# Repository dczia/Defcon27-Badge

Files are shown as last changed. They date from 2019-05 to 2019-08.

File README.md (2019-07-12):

# Defcon27-Badge

```
 ____   ____ ______             ____   ____ ____ _____
|  _ \ / ___|__  (_) __ _      |  _ \ / ___|___ \___  |
| | | | |     / /| |/ _` |_____| | | | |     __) | / /
| |_| | |___ / /_| | (_| |_____| |_| | |___ / __/ / /
|____/ \____/____|_|\__,_|     |____/ \____|_____/_/
```

# Lazer Theramin Synth Badge

This year we wanted to do something different. Our idea is to use two laser time of flight sensors that can measure the distance of your hands moving around infront of the badge to control a synthesizer to create a laser theremin.

- 64Mhz Arm CortexM4F with Bluetooth 5
- 5 Mechanical Clicky Low Profile Key Switches
- Rotary Encoder with Click Button
- OLED Display
- Onboard Speaker and Amplifier!
- 1/8" Headphone Out Audio Jack
- SD Card Storage
- RGB Leds
- 2 SAO / "Shitty Add-On" Connectors

# Hardware Detail

- Rigado BMD-340 aka NRF52 Microconroller
  - Bluetooth, Lots of IO's, Fast, Small, Low Power, and cheap ~ $12
  - https://www.rigado.com/products/modules/bmd-340/

- Laser Time of Flight Sensors - Dev modules are from Adafruit 
  - https://www.adafruit.com/product/3317

- DAC / Amplifier - mediumRehr Audio™

- Speaker - Oval 1watt onboard speaker

- Buttons - Kalih Low Profile White Clicky Keyswitches. Oh yeah. This is the shit right here.
  - https://novelkeys.xyz/collections/switches/products/kailh-low-profile-switches

- Keycaps - Note, the low profile caps are for the Kalih low profile switches only. 
  - https://novelkeys.xyz/collections/keycaps/products/kailh-low-profile-keycaps-blank
  
- LEDs
  - Neopixel RGB

- Screen - SSD1306 OLED

- SD Card

# Software

- Environment is GNU ARM GCC with your choice of IDE

- Programming can be done via a J-Link Segger or by SD Card (coming soon)

- Uses Nordic SoftDevice version XXX

- See [EnvironmentSetup](Software/EnvironmentSetup.md) for more info

# Board

- Designed in KiCad

# Documentation

- [Board Build Guide](BuildGuide.md)
- [EnvironmentSetup](Software/EnvironmentSetup.md)

# Links to relevant information

- [Documentation library - nordicsemi.com](https://www.nordicsemi.com/DocLib)

- DC801 Party Badge - Good source for setting up dev env, and seeing some Rigado code in action - https://github.com/DC801/DC26PartyBadge

- oxvox - Rigado based pwm synth - https://github.com/mediumrehr/oxvox

- Basic audio synthesis with an Arduino - https://makezine.com/projects/make-35/advanced-arduino-sound-synthesis/

- mintysynth - simple arduino synth - https://mintysynth.com/

- Nordic PWM Driver info: https://infocenter.nordicsemi.com/index.jsp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

- PWM Primer - https://provideyourown.com/2011/analogwrite-convert-pwm-to-voltage/

# Devboard pinout

BMD-340-DK Pinout

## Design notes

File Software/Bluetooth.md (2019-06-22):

# DC25 Bluetooth Protocol

So you might have noticed that multiple badges talked to each other this year.  How did we do that?  Well, the magic is in the BLE advertising packet.

This packet can be up to 31 bytes long, and consists of a series of 'blocks'.  Each block starts with a byte that indicates how many bytes follow in this block, next byte is the block type, then the rest of the bytes are the block content.

The key parts of the DC26 and the DC25 protocol before it are the Appearance value, which must be DC19, and the manufacturer block, which defines which badge this is.  The rest of the packet can be whatever you want it to be.

Here's a visual of a packet that my DC801 badge broadcasted:

Advertising Layout

Let's break this down:

General notes:  This is the order the DC801 badge sent the blocks, but in reality the order doesn't matter.

First off, Appearance. 4 total bytes, but the length byte doesn't count, so 03 bytes long.  Type is 0x19 to indicate this is a BLE Appearance block, then the Appearance ID of DC26.  If it was a DC25 badge, the ID would be DC19 - yeah, we changed it up a little

Next up, Flags.  The Flags mark what kind of advertisement this is.  With our flags of 06 we indicate we are general connectable and that we'll show up in bluetooth scans.  Open your phone and look for nearby devices - your DC801 badge will show up there.  We don't offer any actual services, so connecting to the badge is a bit of a honeypit to slow down people attempting to figure out the game protocol.

Next block, Manufacturer.  This block is a little special.  The first two bytes is the manufacturer ID, which is byte swapped 'on the wire' as it were: 0108 is 0801.  Some groups actually registered with the BLE group and got a real ID - check out Bender or Queercon.  We didn't get the paperwork done in time, so we used a fake ID that was not in use for 0801.  Now, there are some bytes that follow.  Those bytes can be any length (up to the 31 total, remember), and can mean anything you want them to mean.  In our case:

0108 - DC801 is the manufacturer
8 bytes - which contains your score, your clan, and a checksum of your score with some bytes scrambled:
 - 0: Command to DCFurs badges - 0x35 indicates rabies infection
 - 1: Score byte 0
 - 2: Score byte 3
 - 3: CRC high byte
 - 4: Score byte 2
 - 5: CRC low byte
 - 6: Score byte 1
 - 7: Clan ID
 
The score can be as big as 32 bytes, unsigned.  I put it through a 'custom' CRC seeded with the polynum 0x0801 to verify that the score hasn't been tampered with - but I know someone is gonna figure that out, but I'm slowing you down a little.  Same for swapping up the bytes of the score.

However, bytes 1-6 are different if the badge is a 'god mode' badge sending a command - see [godmode.c](godmode.c) for more specific info, but we support these commands:

 - Sheep mode - user badge gets stuck in a loop showing sheep pictures
 - Party mode - user badge gets stuck showing an animated sheep and some LEDs
 - Score points - send the user badge some points, + or -
 - Score modifier - send the user a score percentage modifier
 - Beep - make the user badge beep

Last block is a type 09, which is the Long Name.  This part of the BLE stack will show up as the name if you scan for a device.  Again, it's 8 chars, always, padded with 00 if shorter.  Other badges didn't even look at this, it was just for showing up in bluetooth scans.  68616d7374657200 is ASCII 'hamster'.

##Party

The plan was to show a scoreboard at the party, but... time got in the way, so it didn't happen.  Ah well.  Next year.

How did you like it?  Let me know!  [@hamster](http://twitter.com/hamster)

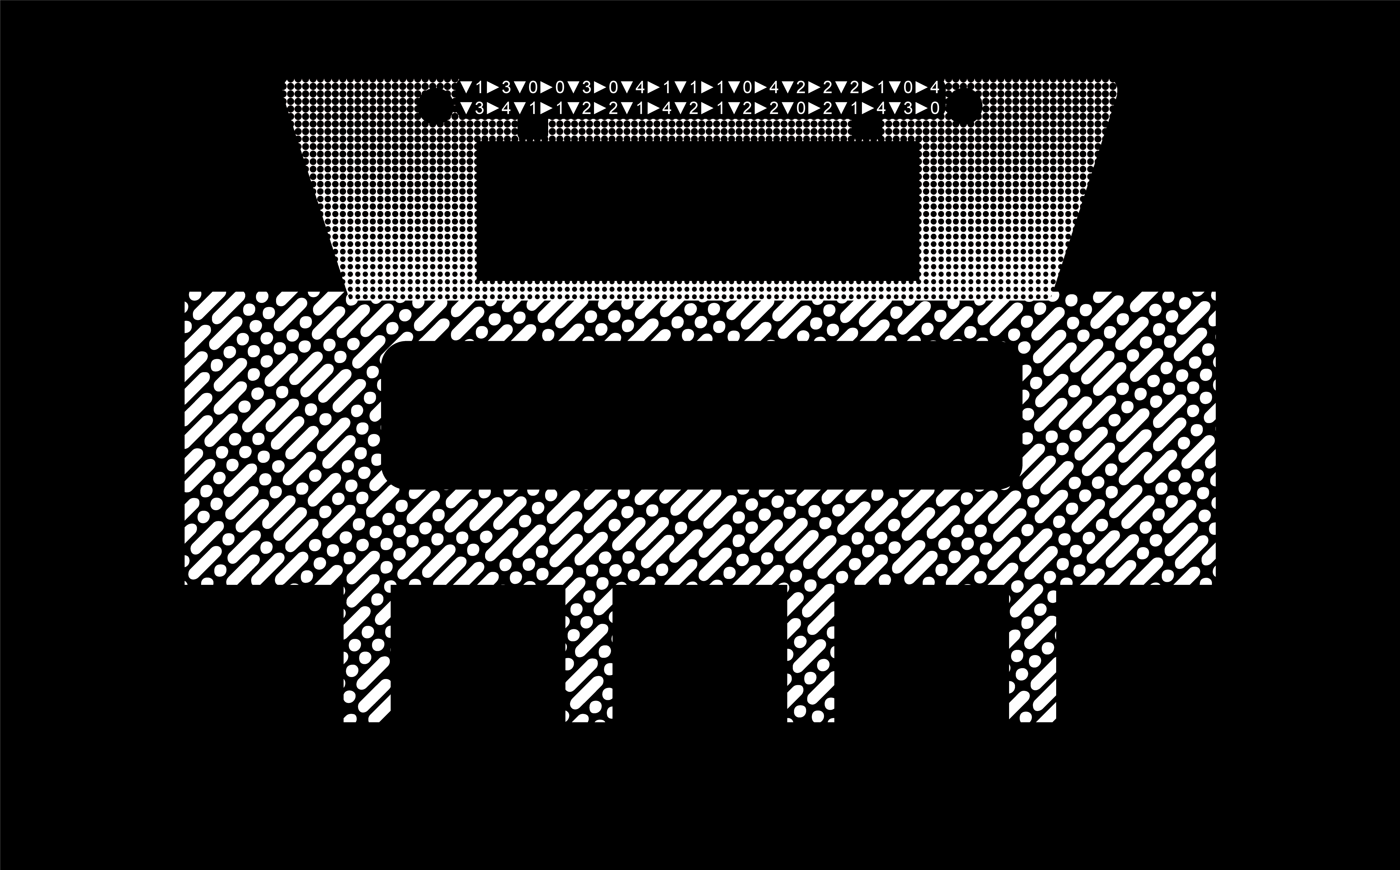
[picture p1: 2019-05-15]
Hardware/Images/silk-art.png

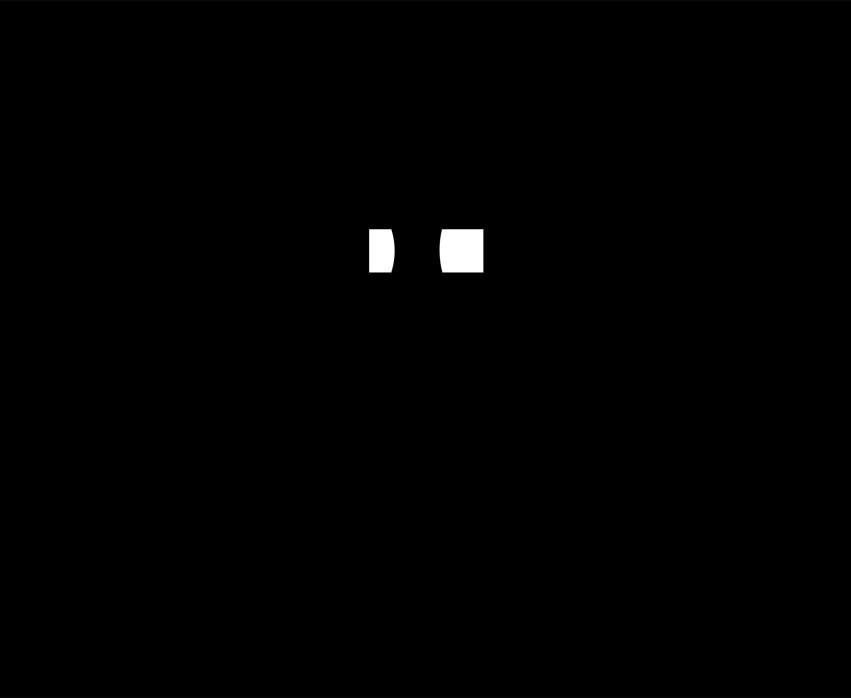
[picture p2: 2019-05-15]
Hardware/Images/copper-reels.png

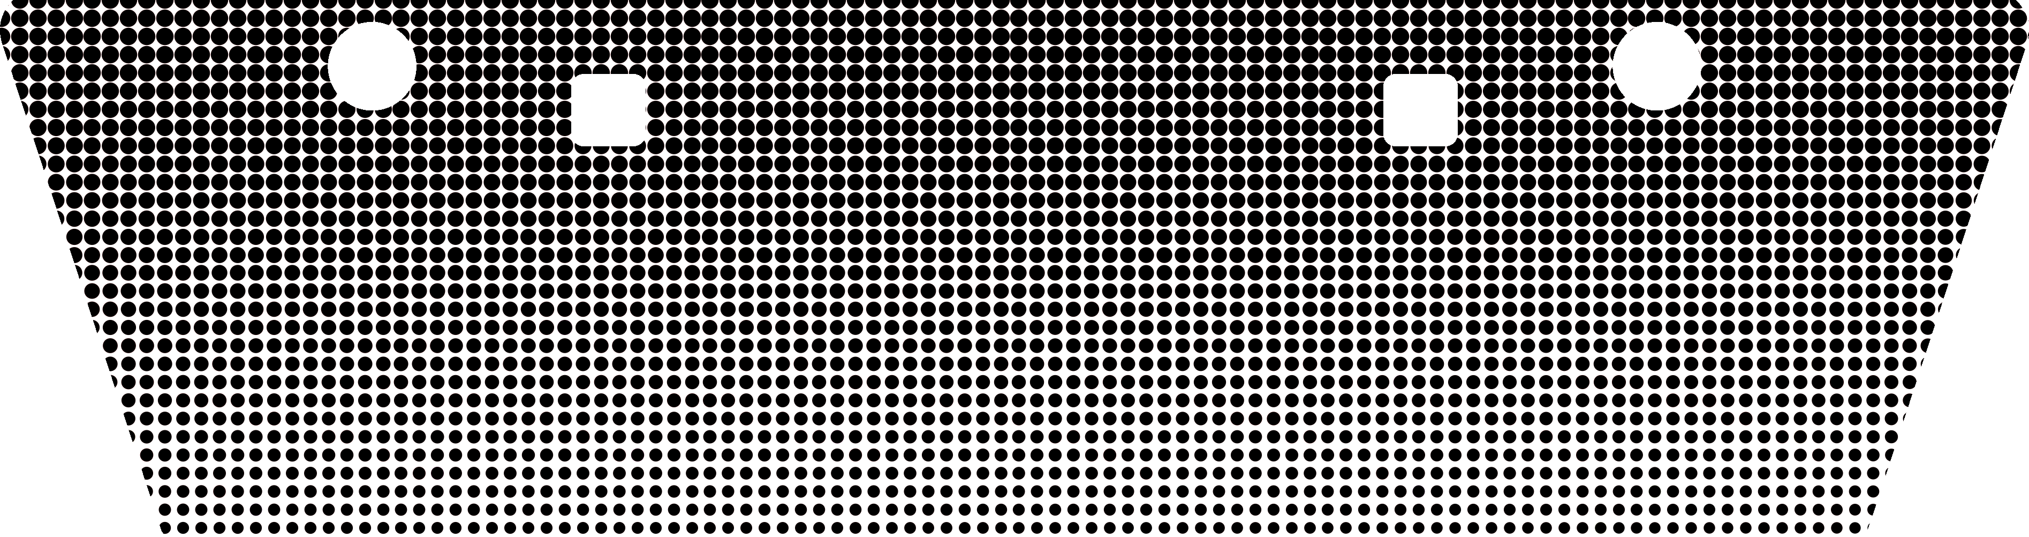
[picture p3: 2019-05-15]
Hardware/Images/halftone2.png

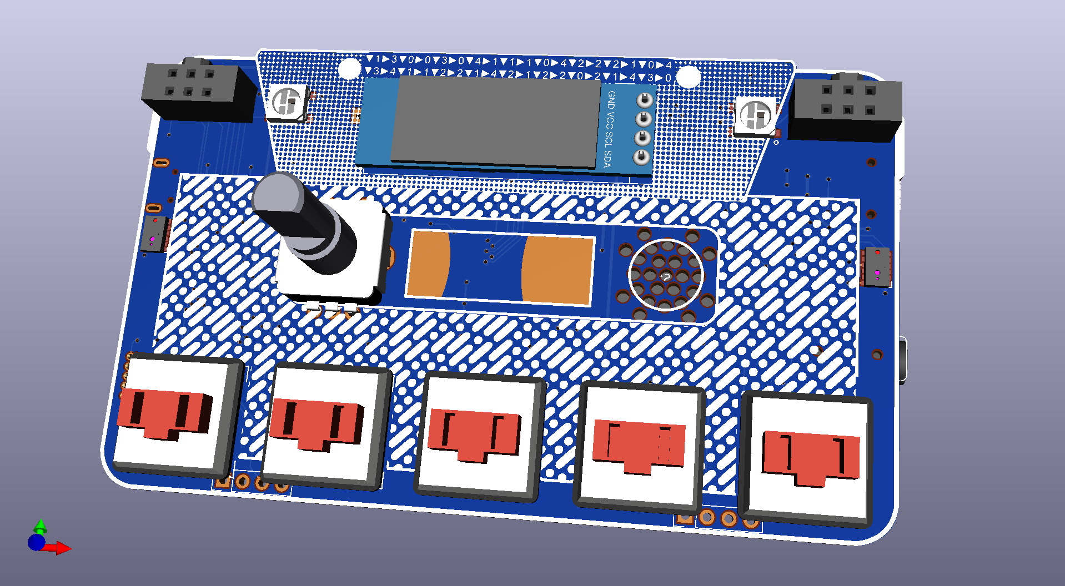
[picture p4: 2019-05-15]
Hardware/Images/laser-theremin-front-4.png

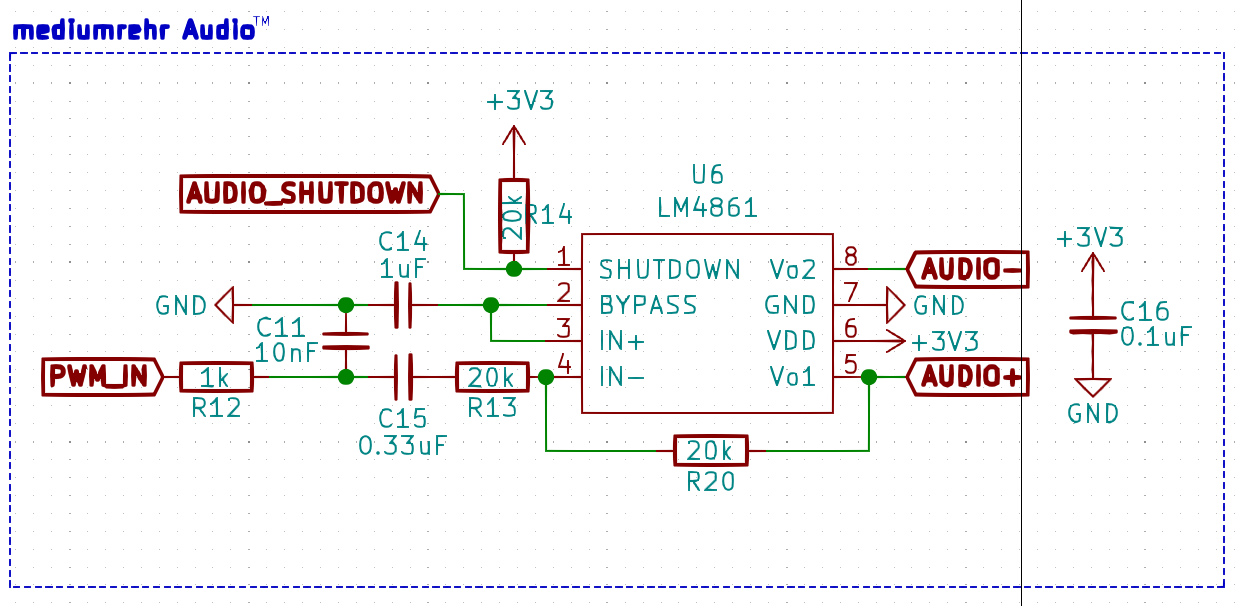
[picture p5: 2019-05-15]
Hardware/Images/mediumrehr-audio.PNG

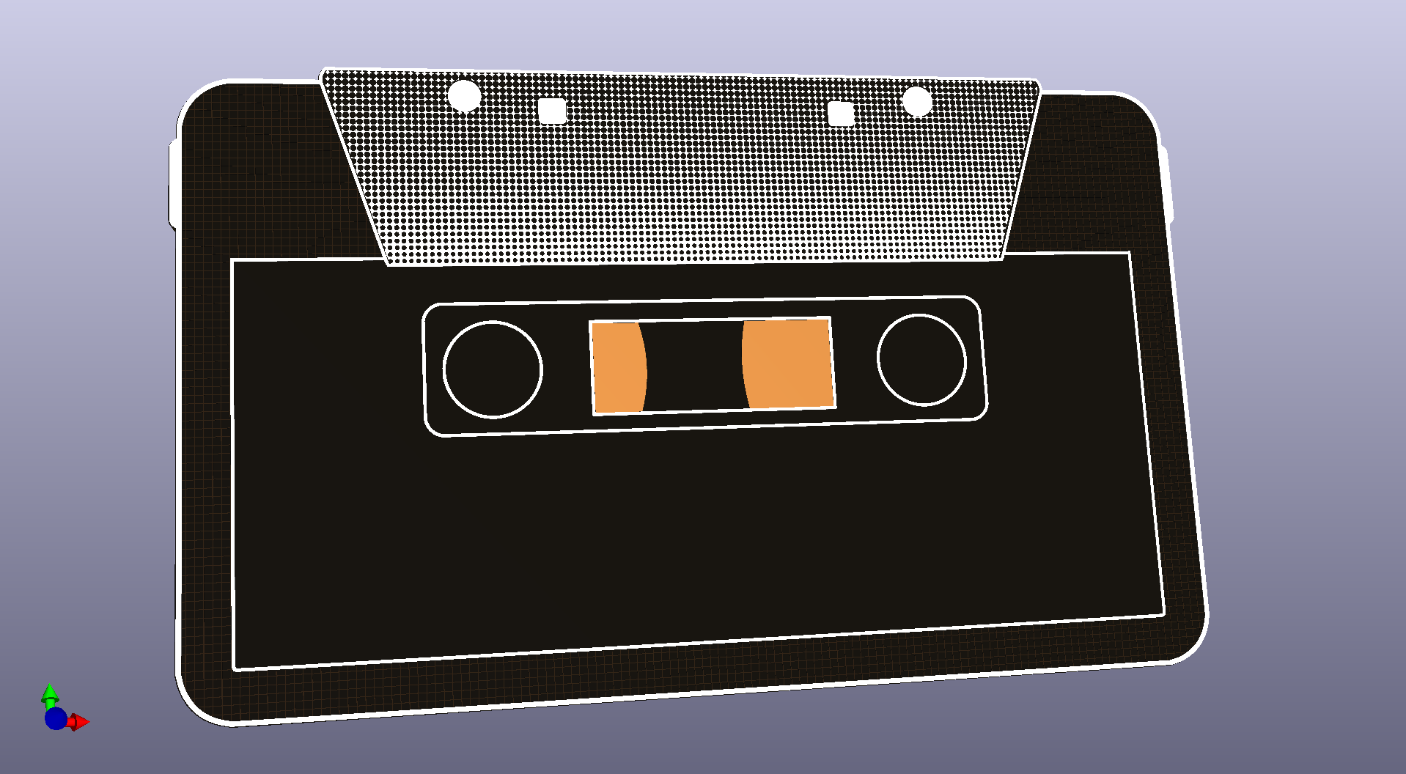
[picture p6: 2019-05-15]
Hardware/Images/laser-theremin-front.png

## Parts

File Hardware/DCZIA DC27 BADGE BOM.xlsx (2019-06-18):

Refdes | Manufacturer | Part Number | Seeed OPL | Other supplier | Description | Package | Cost Each (assumes 100 unit pricing) | Qty per board | Stuff? | QOH | Needed | To Order | Cost Per Board | Qty ordered | Actual Cost | Supplier | Seeed OPL
To Stuff Later
BT1 |  |  |  | https://www.aliexpress.com/item/32323069094.html?spm=a2g0s.9042311.0.0.3da24c4d4QbjF6 | 3xAAA Battery Box |  | 0.28 | 1 |  |  |  |  | 0.28
SW2,SW3,SW4,SW5,SW6 |  | Kaihl Switches |  |  |  |  | 0.66 | 5 |  |  |  |  | 3.3
LS1 |  |  |  | https://www.aliexpress.com/item/20pcs-lot-Acoustic-Speaker-2415-1524-Oval-Tablet-Phone-MP3-Speaker-1W-8-Ohms-L24MMxW15MM/1680397983.html | Speaker, 24x15mm |  | 0.33 | 1 |  |  |  |  | 0.33
OLED |  |  |  |  | OLED display
Virtual, Non-stuff
J1 |  |  |  |  | 2x10 1.27 header, JTAG |  |  |  | N |  |  |  | 0
J5,J9 |  |  |  |  | Rack |  |  |  | N
J7 |  |  |  |  | OLED connector |  |  |  | N
J13 |  |  |  |  | TagConnect |  |  |  | N
J6,J8,J10,J11,J12 |  |  |  |  | Test points |  |  |  | N
X1,X2 |  |  |  |  | SAO 1.69bis |  |  |  | N |  |  |  | 0
R21,R22 |  |  | RC0402JR-074K7L |  | 4.7k DNS | 0402 | 0.0008 | 2 |  |  |  |  | 0.0016
SW7 |  |  | 311130001 |  | Rotary encoder, 12mm DNS |  | 0.61 | 1 |  | m |  |  | 0.61
Stuff at Fab
C1,C2,C7,C10,C16,C17,C18 |  |  | 302010024 |  | 0.1uF Cap | 0402 | 0.01 | 12 |  |  |  |  | 0.12
C3,C5,C15 |  |  | 302010003 |  | 1uF | 0402 | 0.01 | 3 |  |  |  |  | 0.03
C4,C6 |  |  | 302010019 |  | 4.7uF | 0402 | 0.01 | 2 |  |  |  |  | 0.02
C8 |  |  | 302010171 |  | 22uF | 0805 | 0.024 | 1 |  | m |  |  | 0.024
C9 |  |  | 302010005 |  | 1nF | 0402 | 0.01 | 1 |  |  |  |  | 0.01
C11 |  |  | 302010006 |  | 10nF | 0402 | 0.01 | 1 |  |  |  |  | 0.01
C12,C13 |  |  | 302010007 |  | 47pf | 0402 | 0.01 | 2 |  |  |  |  | 0.02
C14 |  |  | CL05A334KQ5NNNC |  | 0.33uF | 0402 | 0.0115 | 1 |  | m |  |  | 0.0115
D1,D12,D13 |  | B5819W | 304020034 |  | Schottky | SOD-123 | 0.023 | 1 |  |  |  |  | 0.023
D2 |  | CESD5V0AP | 304050003 |  | TVS diode | SOT-23 | 0.032 | 1 |  | skip |  |  | 0.032
D3,D4 |  | 1N4148 | 1N4148WS |  | General purpose diode | SOD-323 | 0.0149 | 2 |  |  |  |  | 0.0298
D7,D8,D9,D10,D11 |  |  | 19-217/R6C-AL1M2VY/3T |  | Red LED | 0603 | 0.0232 | 5 |  | m |  |  | 0.116
J2 |  | TF-01 | 320090008 |  | MicroSD socket |  | 0.109 | 1 |  |  |  |  | 0.109
J3 |  |  | 320010000 |  | USB micro, 'with holes' |  | 0.118 | 1 |  | m |  |  | 0.118
J4 |  |  | 320040003 |  | Headphone jack |  | 0.185 | 1 |  |  |  |  | 0.185
L1 |  |  | 303010114 |  | 4.7uH inductor | 3x2.1mm | 0.045 | 1 |  |  |  |  | 0.045
Q1 |  | NCE3407A | 305030010 | FDN360P | P-channel mosfet | SOT-23 | 0.047 | 1 |  |  |  |  | 0.047
Q2,Q3 |  | BSS138 | 305030000 |  | N-ch mosfet | SOT-323 | 0.033 | 2 |  |  |  |  | 0.066
R1,R2,R3,R6,R7,R13,R14,R15,R16,R17,R18,R19,R25 |  |  | RC0402JR-0710KL |  | 10k | 0402 | 0.0007 | 10 |  |  |  |  | 0.007
R4 |  |  | 0402WGF8063TCE |  | 806k | 0402 | 0.0013 | 1 |  |  |  |  | 0.0013
R5 |  |  | RC0402JR-072ML |  | 2M | 0402 | 0.0013 | 1 |  |  |  |  | 0.0013
R8,R9 |  |  | RC0402FR-0747KL |  | 47k | 0402 | 0.0009 | 2 |  |  |  |  | 0.0018
R10,R11 |  |  | RC0402FR-0727RL |  | 27R | 0402 | 0.0015 | 2 |  |  |  |  | 0.003
R12 |  |  | RC0402JR-071KL |  | 1k | 0402 | 0.0017 | 1 |  |  |  |  | 0.0017
R23 |  |  | RC0402FR-07536KL |  | 536k 1% | 0402 | 0.0006 | 1 |  |  |  |  | 0.0006
R24 |  |  | 0402WGJ0124TCE |  | 120k 1% | 0402 | 0.0007 | 1 |  |  |  |  | 0.0007
R26,R27,R28,R29,R30 |  |  | RC0402FR-0733RL |  | 33R | 0402 | 0.0016 | 5
R20,R31 |  |  | RC0402JR-0720KL |  | 20k | 0402 | 0.0008 | 2
U1 |  | XC6221A282MR-G | XC6221A282MR-G |  | 2.8v vreg | SOT-25 | 0.0841 | 1 |  | m |  |  | 0.0841
U2 |  | PAM2305DABADJ | PAM2305AABADJ |  | 3.3 buck vreg | SOT-23-5 | 0.1316 | 1 |  |  |  |  | 0.1316
D5,D6 |  | SK6812 |  |  |  |  |  |  |  | skip
SW1 |  | JS102011SAQN |  | Digikey 401-1999-1-ND Mouser 611-JS102011SAQN |  |  | 0.4801 | 1 |  | skip |  |  | 0.4801
U3 |  | BMD-340 |  | On hand |  |  | 8 | 1 |  | m |  |  | 8
U4,U5 |  | VL6180X |  | Digikey 497-14702-1-ND Mouser 511-VL6180XV0NR/1 |  |  | 3.7472 | 2 |  | m |  |  | 7.4944
U6 |  | LM4861 |  | Digikey 296-38566-1-ND Mouser 926-LM4861MX/NOPB |  | SOIC-8 | 0.9381 | 1 |  |  |  |  | 0.9381
 |  |  |  |  |  |  |  |  |  |  |  | Total | 22.6836
 |  |  |  |  |  |  |  |  |  |  | 75 | Boards | 114.21 | 1.5228
 |  |  |  |  |  |  |  |  |  |  |  | PCBA Cost | 1794 | 23.92
 |  |  |  |  |  |  |  |  |  |  | 0.93 | audio | 69.75
 |  |  |  |  |  |  |  |  |  |  | 7.4944 | laser | 562.08
 |  |  |  |  |  |  |  |  |  |  | 7 | bmd340 | 525
 |  |  |  |  |  |  |  |  |  |  | 1 | batteries | 75
 |  |  |  |  |  |  |  |  |  |  | 0.5 | batt box | 37.5
 |  |  |  |  |  |  |  |  |  |  | 3.25 | Keys | 243.75
 |  |  |  |  |  |  |  |  |  |  |  | Total | 3421.29 | 45.6172

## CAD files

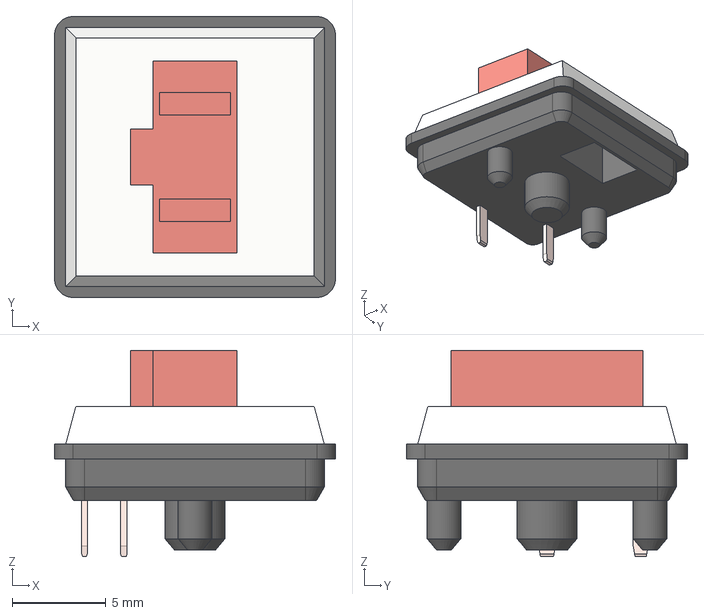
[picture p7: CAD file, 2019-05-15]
Hardware/3D/Kailh Choc v0.step
15.0 x 15.0 x 11.0 mm

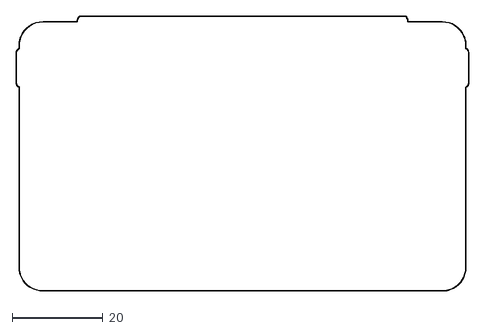
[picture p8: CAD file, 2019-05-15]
Hardware/Images/outline.dxf
99.4 x 60.4

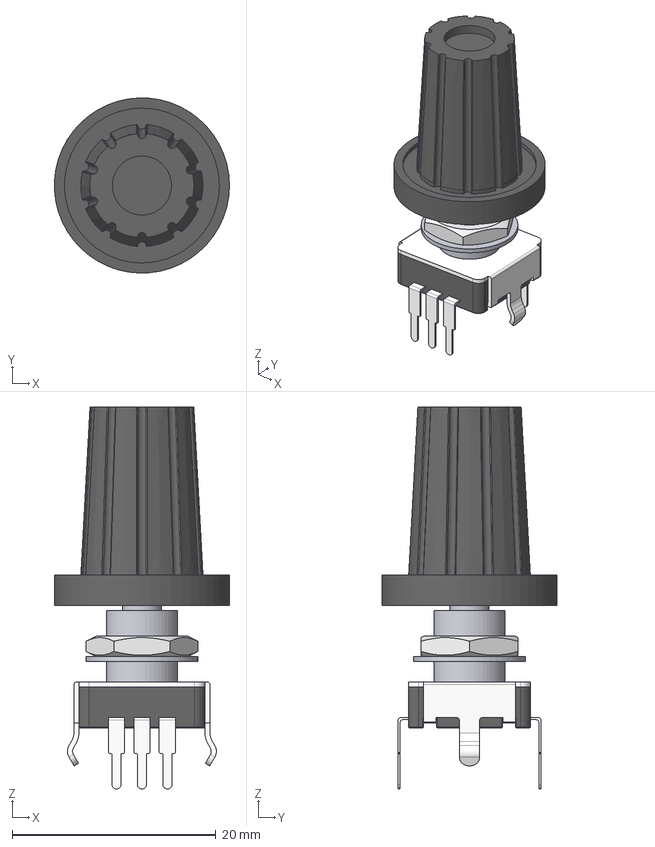
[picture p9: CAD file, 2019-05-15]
Hardware/3D/12mm Incremental Encoder - BOURNS PEC11S.stp
17.2 x 17.2 x 37.5 mm
12mm Incremental Encoder Base
12mm Incremental Encoder Pin x 5
12mm Incremental Encoder Anti-Rotation Plate
12mm Incremental Encoder Threaded Tube
12mm Incremental Encoder Washer
M7x0.75 Hex Nut
12mm Incremental Encoder Shaft
12mm Incremental Encoder Cap

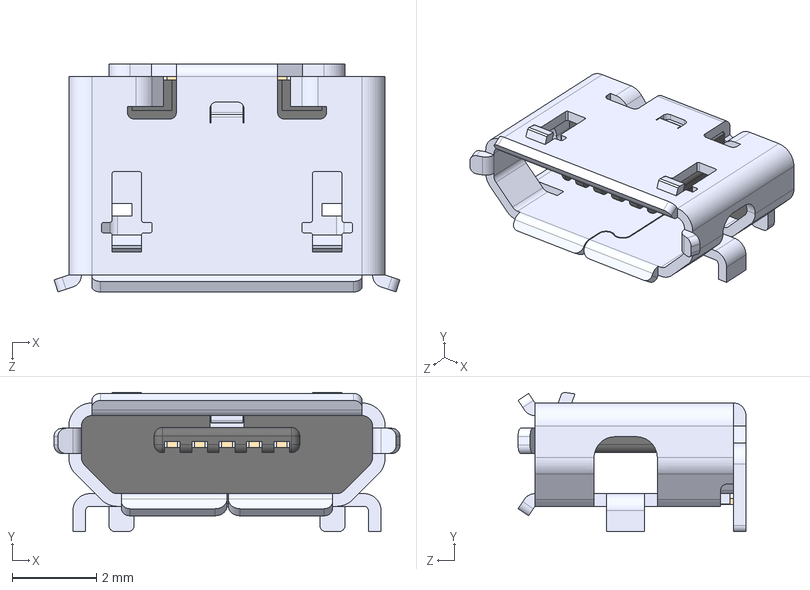
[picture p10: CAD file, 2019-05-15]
Hardware/3D/MicroUSB.STEP
8.20 x 3.30 x 5.40 mm

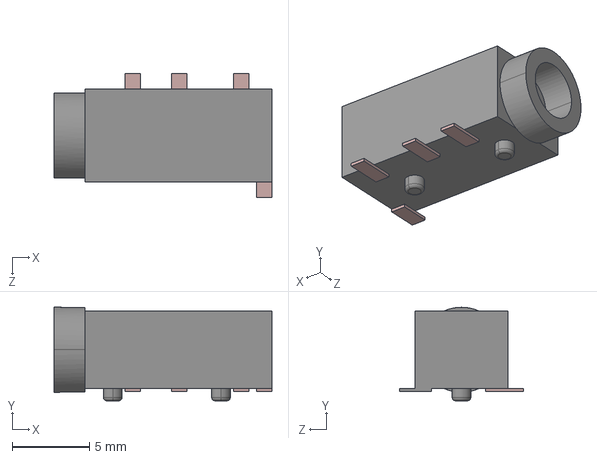
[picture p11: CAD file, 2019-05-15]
Hardware/3D/FemaleAudioJack.STEP
14.1 x 6.05 x 8.00 mm

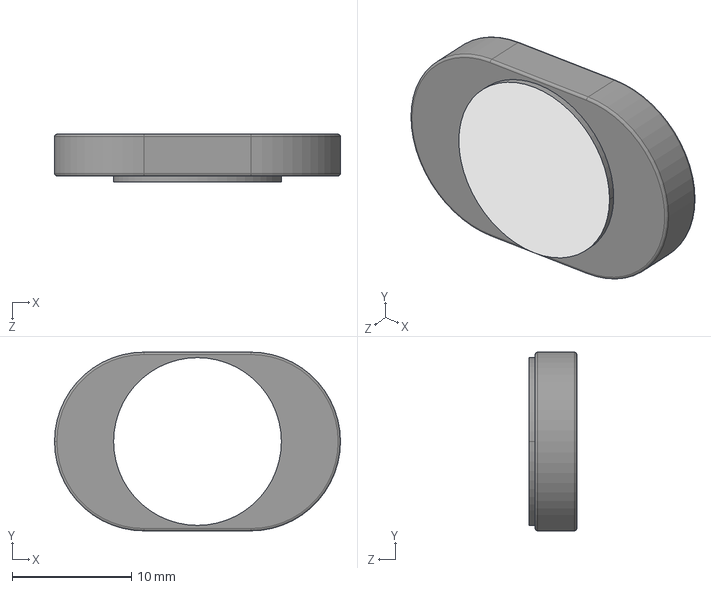
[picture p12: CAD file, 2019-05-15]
Hardware/3D/Speaker-24x15.STEP
24.0 x 15.0 x 4.00 mm

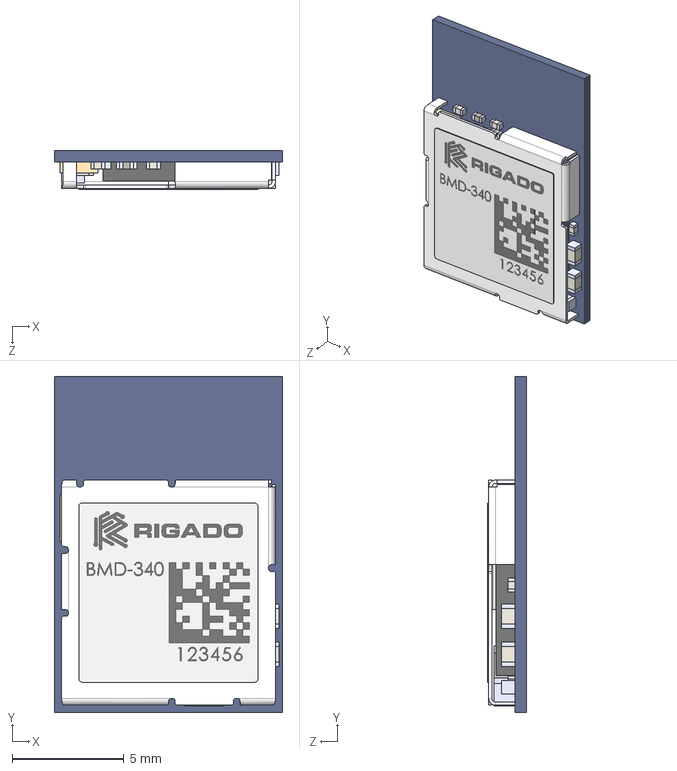
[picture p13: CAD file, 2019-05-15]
Hardware/3D/BMD-340.STEP
10.2 x 15.0 x 1.73 mm

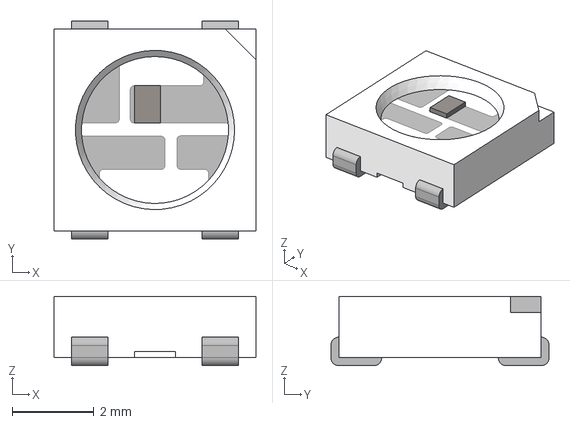
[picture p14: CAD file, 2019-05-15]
Hardware/3D/WS2812_RGB_LED_updated.stp
4.95 x 5.35 x 1.70 mm

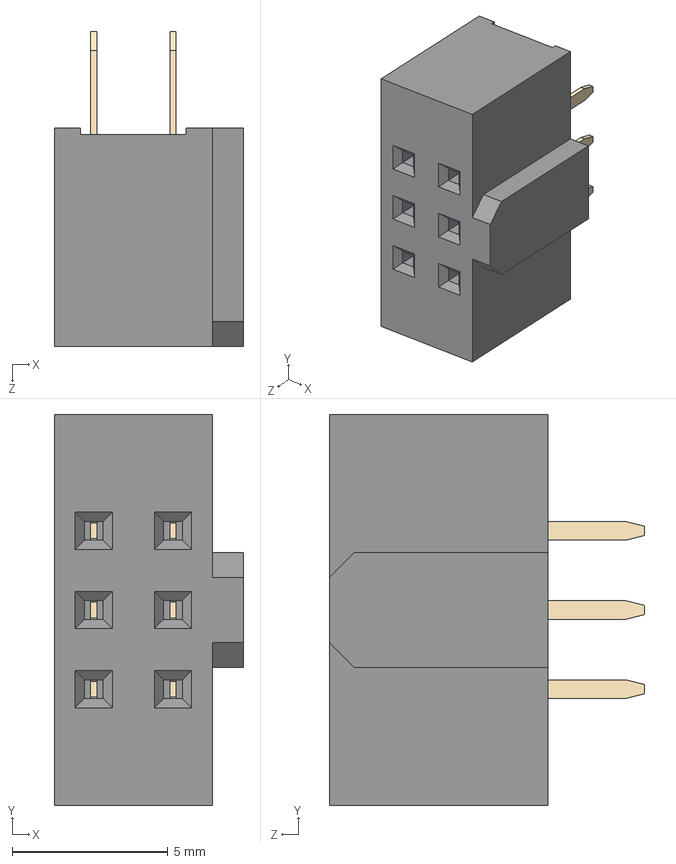
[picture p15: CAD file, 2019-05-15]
Hardware/3D/PinSocket_2x03_P2.54mm_Vertical.step
6.08 x 12.5 x 10.1 mm

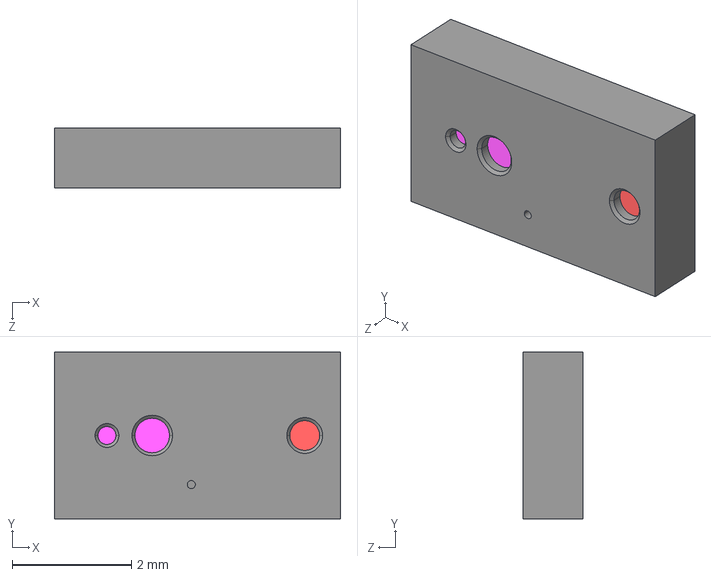
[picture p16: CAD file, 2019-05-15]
Hardware/3D/VL6180X.STEP
4.80 x 2.80 x 1.00 mm

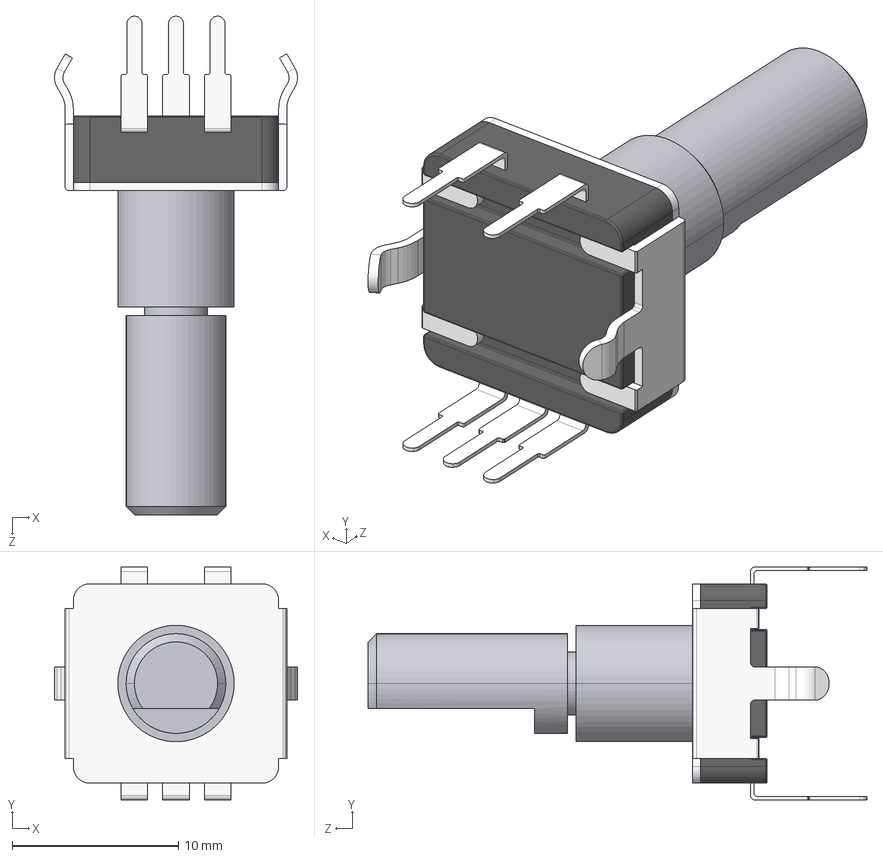
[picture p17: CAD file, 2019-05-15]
Hardware/3D/12mm Incremental Encoder - BOURNS PEC11S - No Knob.STEP
14.6 x 14.0 x 30.0 mm
12mm Incremental Encoder Base.stp
12mm Incremental Encoder Pin.stp x 5
12mm Incremental Encoder Anti-Rotation Plate.stp
12mm Incremental Encoder Threaded Tube.stp
12mm Incremental Encoder Shaft.stp

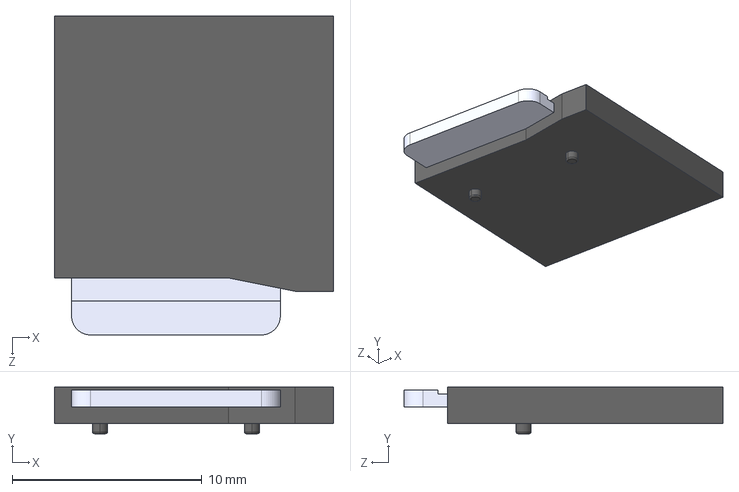
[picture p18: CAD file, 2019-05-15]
Hardware/3D/MicroSD.STEP
14.7 x 2.45 x 16.8 mm

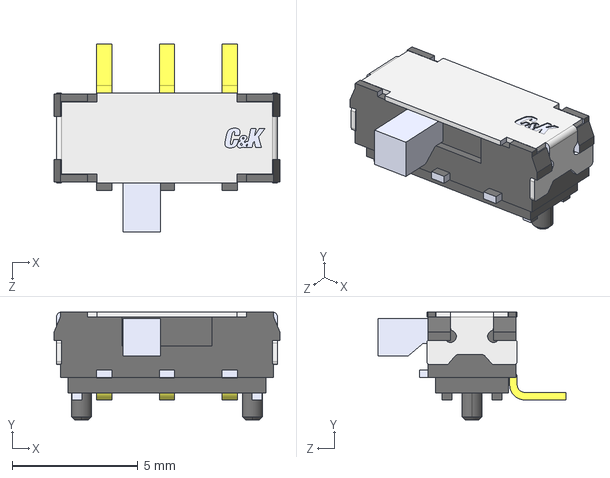
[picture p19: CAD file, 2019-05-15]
Hardware/3D/JS102011SAQN.stp
9.00 x 4.30 x 7.50 mm

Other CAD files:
Hardware/3D/FemaleAudioJack.SLDPRT
Hardware/3D/JS102011SAQN.SLDPRT
Hardware/3D/MicroSD.SLDPRT
Hardware/3D/MicroUSB.SLDPRT
Hardware/3D/PinSocket_2x03_P2.54mm_Vertical.SLDPRT
Hardware/3D/Speaker-24x15.SLDPRT
Hardware/3D/VL6180X.SLDPRT

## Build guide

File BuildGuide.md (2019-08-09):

# DCZia 2019 Badge Build Guide

Rough draft of build guide

## Parts List

The following parts should be included with your badge:

- Partially asasembled badge PCB
- 5x Mechanical "low profile" Keyswitches
- 5x keycaps
- 1 OLED Screen
- 1 Rotary Encoder
- 1 Speaker
- 1 Battery Box
- 3x AAA Batteries
- 2x SAO Headers
- Please note, no SD card is included, this is optional
- Stickers
- Lanyard

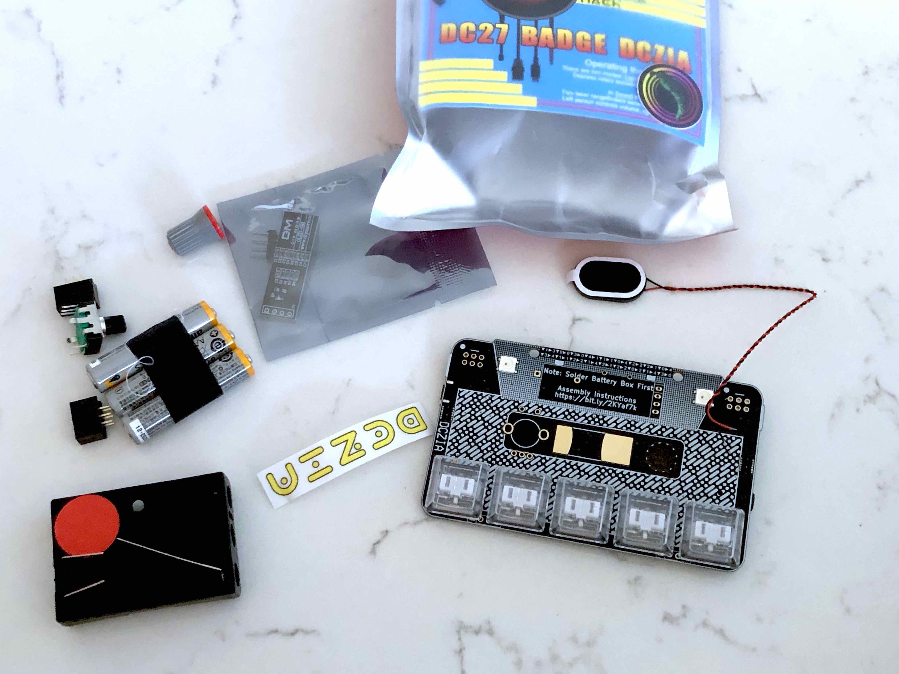
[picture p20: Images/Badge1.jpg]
Badge contents


## Build Instructions

- Step 1. Solder on keyswitches
- Step 2. Solder on rotatry encoder
- Step 3. Solder on battery box
  - **Note** If you did solder on the battery box first, genly bend it upwards to access the components you need to solder underneath it.
- Step 4. Attach screen
  - **Note** Mount the header to the board putting the long legs through the four holes from the back of the pcb. The black plastic part of the header should lay flat on the back of the pcb. Solder the display to the long legs from the front, this way the screen will lay flat on the font of the pcb.
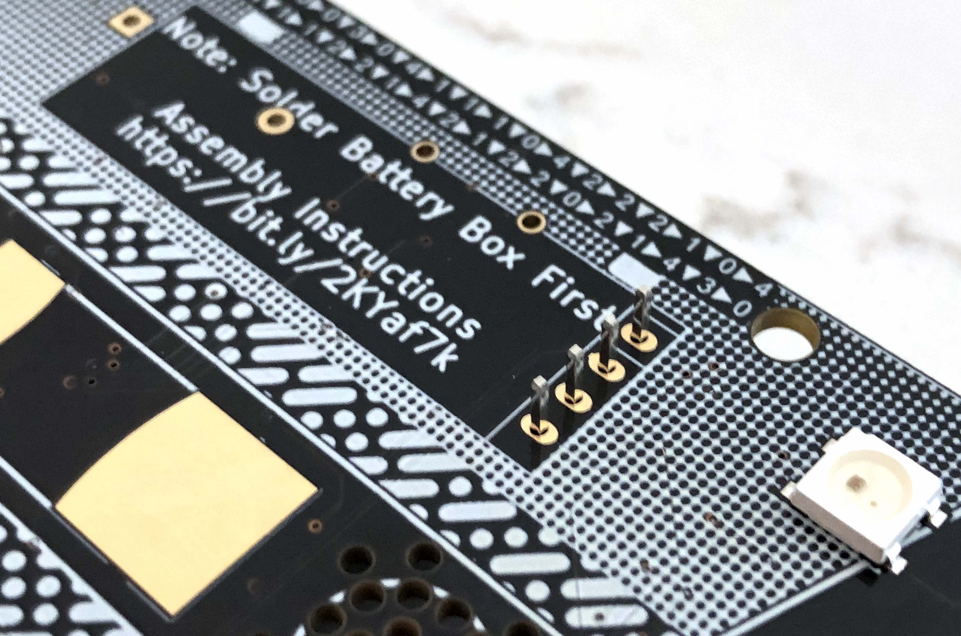
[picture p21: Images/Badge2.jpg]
  
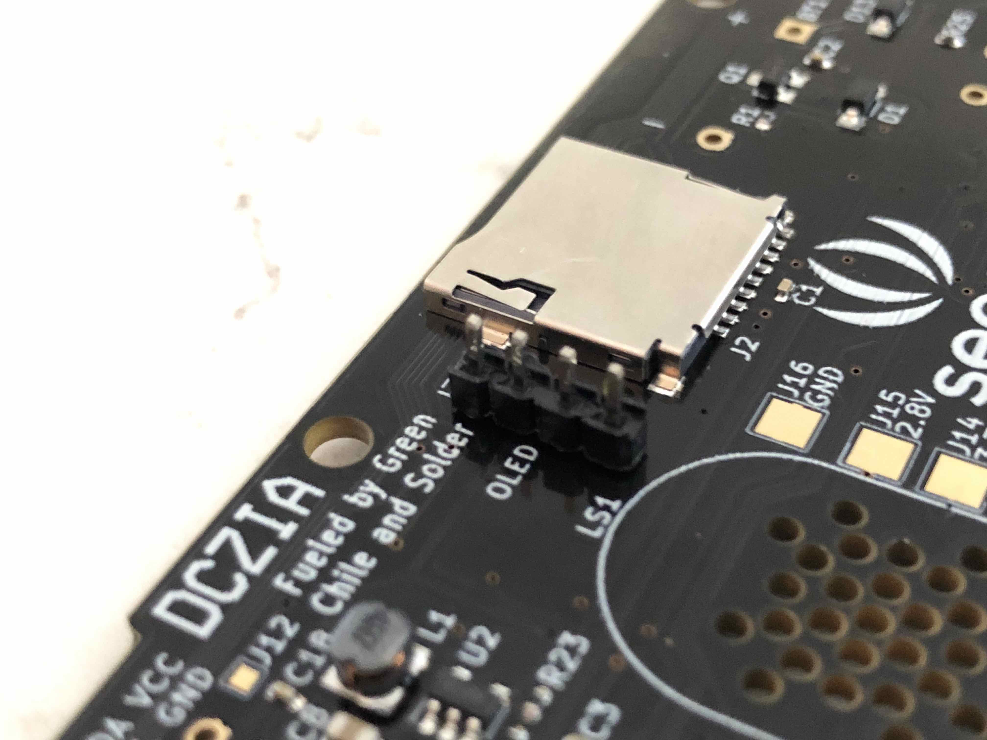
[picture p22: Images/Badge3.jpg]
  
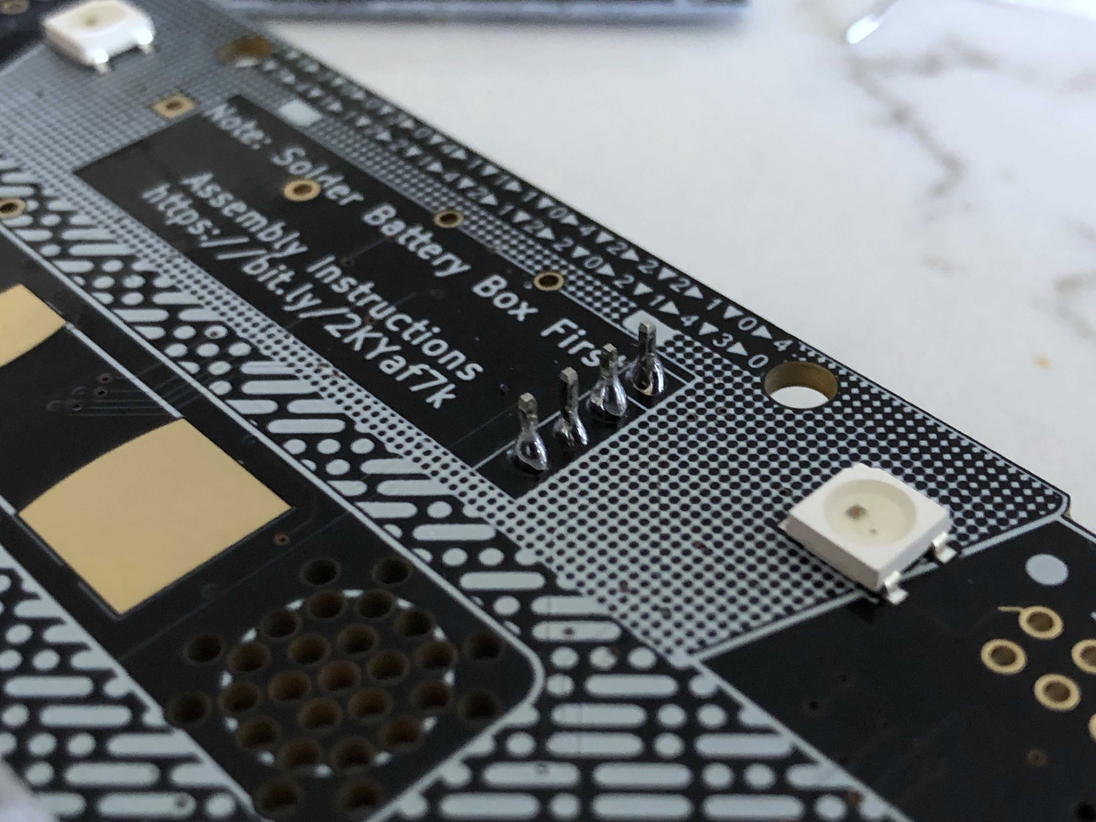
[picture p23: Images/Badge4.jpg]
  
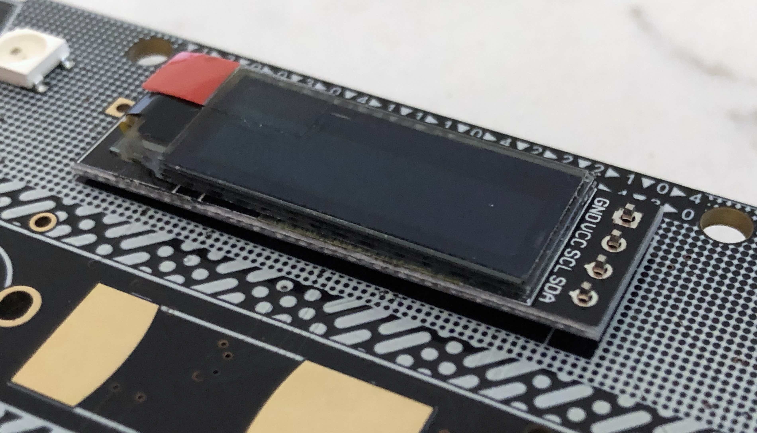
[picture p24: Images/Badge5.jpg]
  
- Step 5. Attach SAO Headers
  - If you wish to use SAO's solder the two headers to the front of the pcb with the notch pointing up
- Step 6. Attach Speaker
  - The positive (RED) and negative (BLACK) wires of the speaker get soldered to the two square pads on the back of the badge on the left side of the pcb looking at it from the rear. Then take the sticky tape backing off the speaker and attach it centered on the prefroated holes on the back of the board.
  - You can gently stuff the extra speaker wire under the battery box if you did not trim it.
- Step 7. Cut the DCZIA sticker and trim into individual D C Z I A stickers and place on the keycaps
- Step 8. Install Batteries
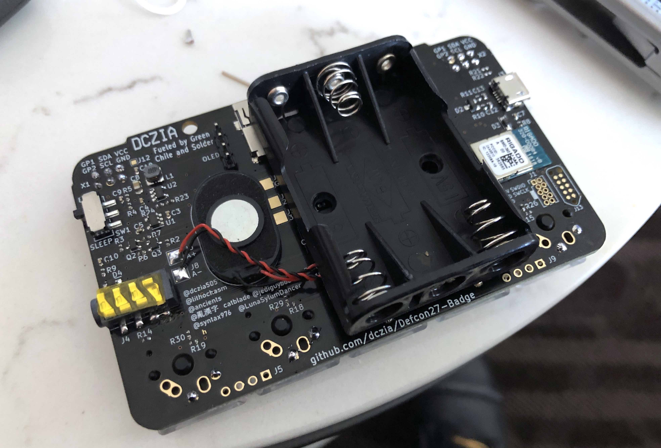
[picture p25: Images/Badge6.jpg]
  
- NOTE - The headphone jack does not work as is,we will post a fix. The jack did not match the footprint we used. Sorry!
- Also Note, if your speaker is really really quiet, please contact us.
- Also Also Note, The battery box is a bit flimsy, so your batterys may jostle and reboot the badge or fly out if the badge is bumped around alot.

## Badge User Manual

The badge by default boots into LED Mode. Presing the D C Z I A keys will change the key light patterns, and colors of the top RGB leds. Placing your hands 2 - 25 cm above the left and right sides of the badge will modify the brightness and color of the corresponding LEDs.

Pressing down on the top of the rotary encoder (it will click when you have activated the button) will change sound modes. The main modes will be LED Mode, Theramin Mode, and Fixed Volume Mode (Loud Mode). 

Looking at the front of the badge with the screen at the top, the left distance sensor will affect volume, and the right sensor will change pitch. Pressing the keys will change waveforms (Square Wave, Sine Wave, Triangle Wave, Sawtooth, and PWM). Rotating the rotary encoder will change the range of pitch that the right sensor will modify.

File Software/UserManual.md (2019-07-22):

Thanks for purchasing our 2019 Badge!

*Operation*

The badge has two modes of operation, light mode and sound mode. Clicking in the rotary encoder will switch between the two.

The buttons along the bottom will switch light patterns or play sounds in their coresponding modes.

In sound mode, the two lazer rangefinders on the sides of the badge will measure how far away your hands are from them. The left sensor will control volume, and the right sensor will control sound.

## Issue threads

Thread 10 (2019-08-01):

Collapse Sound modes to the key switches and not encoder modes

lithochasm, 2019-08-01:
Lets move hold / fixed / doom mode to key switches and not encoder clicks if possible

mediumrehr, 2019-08-01:
hmm the plan was to use the the keys to change waveform and the encoder to change octave. i guess we could use first three keys (DCZ) to change audio mode (fixed, hold, doom) and the last two (IA) to adjust octave. then the encoder could change waveform, or we could flip that and encoder would do octave and IA buttons cycle waveform, or we just get rid of octave changing.

lithochasm, 2019-08-01:
Now that I hear your plan I think it’s cleaner to go with that. Do we need
hold mode? I just wanted to reduce the number of clicks people had to make
in case they need to transition to a quiet mode quickly.

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

mediumrehr, 2019-08-01:
fixed volume makes sense to me. the others don't seem like they need to be modes to me. i think it'd be cool to make doom more of an easter egg. maybe holding all the keys down? something you'd have to try to get into, it's unlikely it'd just get pressed by accident.

lithochasm, 2019-08-01:
That’s a good idea, I like it

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

Ancient123, 2019-08-02:
I like the Doom mode as an easter egg thing. 👍
I am down with removing hold mode, I was just playing around with stuff.

lithochasm, 2019-09-19:
Good job folks. Closing this issue.

Closed 2019-09-19.

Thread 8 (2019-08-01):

Doom Mode uses delays so it does not exit cleanly

lithochasm, 2019-08-01:
Clicking the encoder does not reliably exit to the next mode

mediumrehr, 2019-08-03:
fixed!

Closed 2019-08-03.

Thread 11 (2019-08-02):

Changing LED speeds does not work properly

lithochasm, 2019-08-02:
If you call led_animation(speed) you need to stop the timer then restart it before it will work properly. However when this occurs, the default led Cylon speed gets messed up. I did something wrong, and will investigate it at a later time. For now there is one led speed in use for all modes.

lithochasm, 2019-09-19:
N/A

Closed 2019-09-19.

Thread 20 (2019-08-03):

buttons need debouncing

mediumrehr, 2019-08-03:
when clicking encoder button, modes are sometimes skipped because of there isn't any debouncing. idk how critical it is to fix right now, since with only 2 or 3 modes so it's not _that_ much of a pain. could easily through in delays, but that means delays (might not be that bad).

Closed 2019-08-03.

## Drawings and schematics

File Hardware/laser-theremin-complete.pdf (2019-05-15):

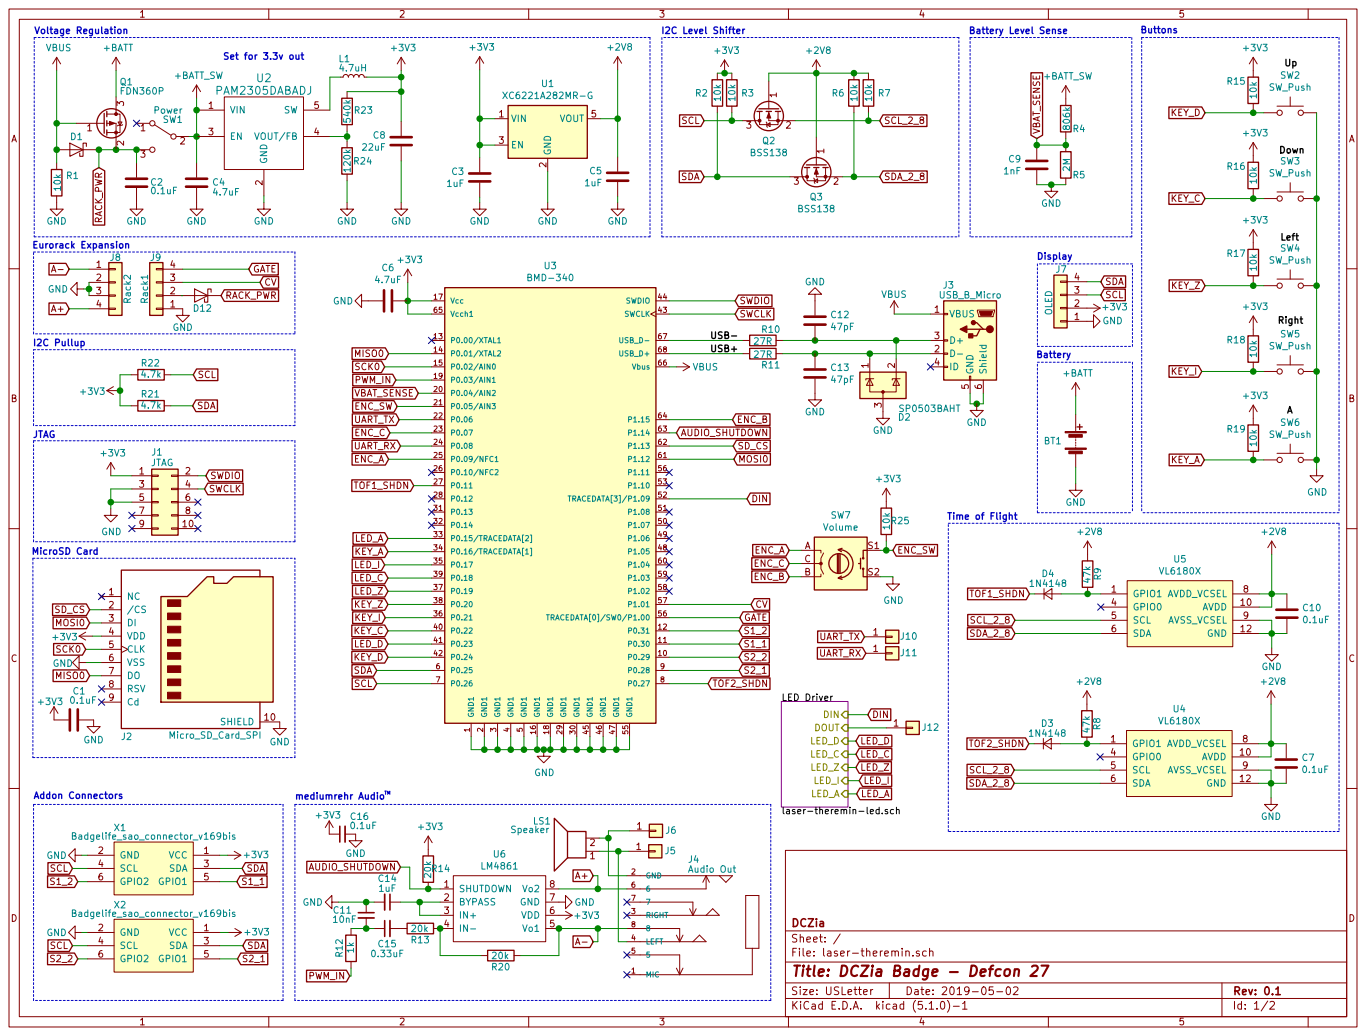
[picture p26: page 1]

2 EN 3 VOUT/FB 4 SW 5 U2 PAM2305DABADJ

5 GND1 55 P1.11 56 TRACEDATA[0]/SW0/P1.00 56 P1.14 63 P1.15 64 P0.28 9 P0.29 10 P0.30 11 P0.31 12 Vcc 17 P0.19 37 P0.20 38 P0.18 39 P0.22 40 P0.23 41 P0.24 42 SWCLK 43 P1.05 48 P1.06 49 P1.07 50 P1.08 51 TRACEDATA[3]/P1.09 52 P1.10 53 P1.01 57 P1.02 58 P1.03 59 P0.25 6 P1.04 60 P1.12 61 P1.13 62 Vcch1 65 Vbus 66 USB_D- 67 USB_D+ 68 P0.26 7 P0.27 8 U3 BMD-340 VBUS GND

Id: 1/2 Title: DCZia Badge - Defcon 27

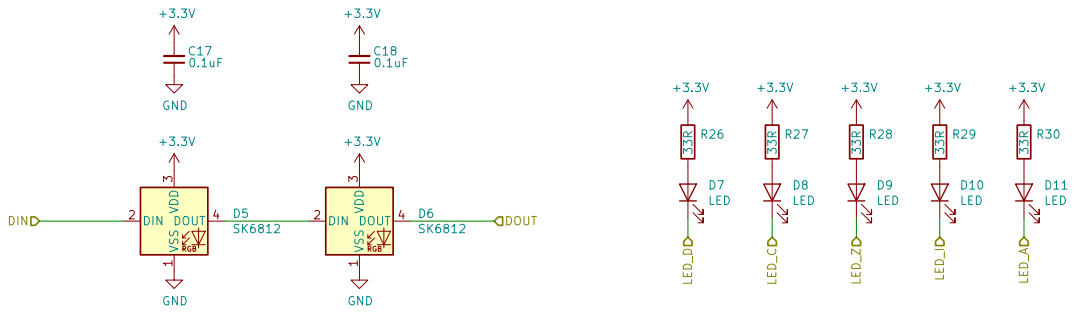
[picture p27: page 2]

File: laser-theremin-led.sch Sheet: /LED Driver/ DC801 GND GND

3 DOUT 4 D5SK6812 DIN DOUT VSS RGB 1 DIN 2 VDD

Id: 2/2 Title: HCRN - DC801 Defcon 27 Badge

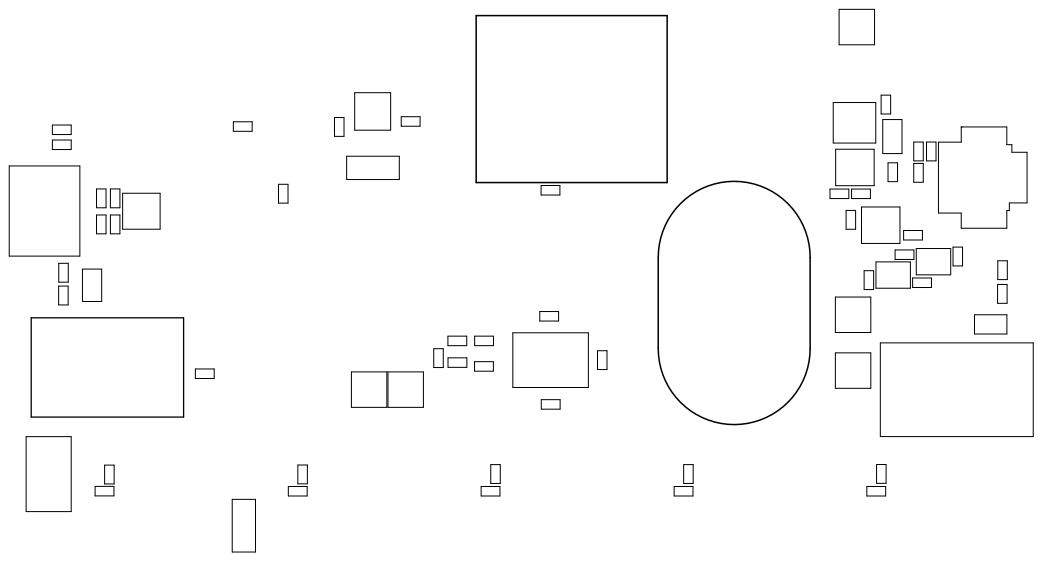
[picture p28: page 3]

File: laser-theremin.kicad_pcb Sheet:
Id: 1/1 Title:

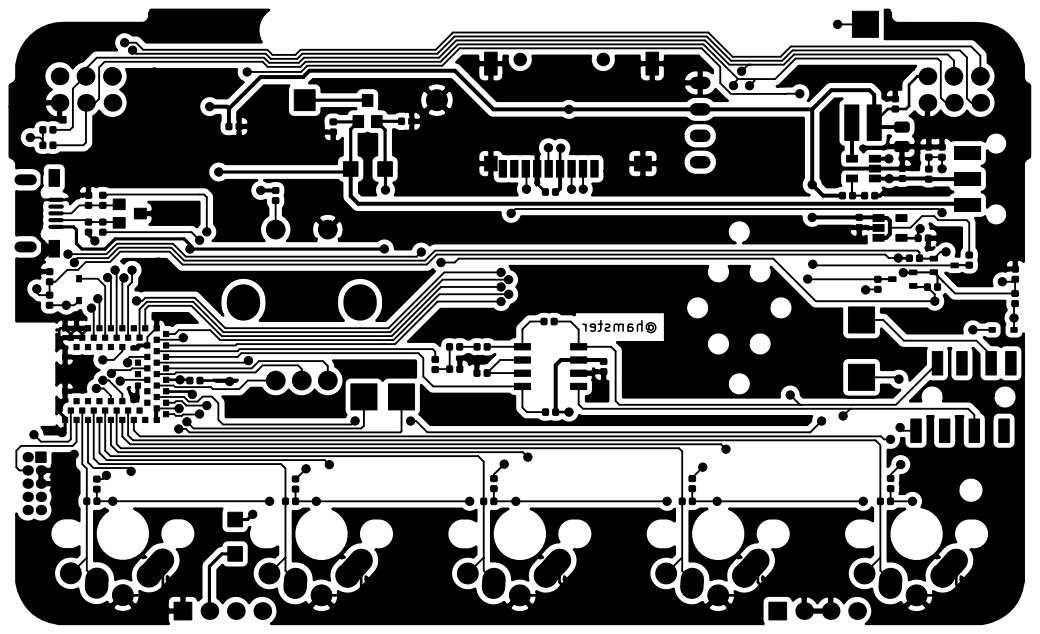
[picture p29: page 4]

File: laser-theremin.kicad_pcb Sheet: @hamster

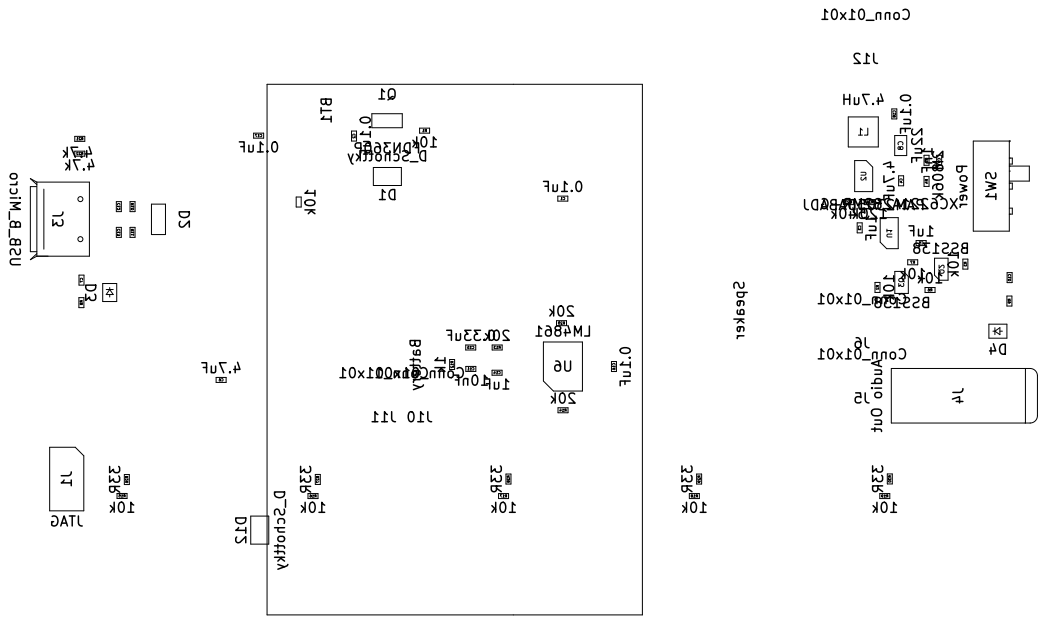
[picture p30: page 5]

L1 FDN360P Q1
File: laser-theremin.kicad_pcb Sheet: Battery BT1

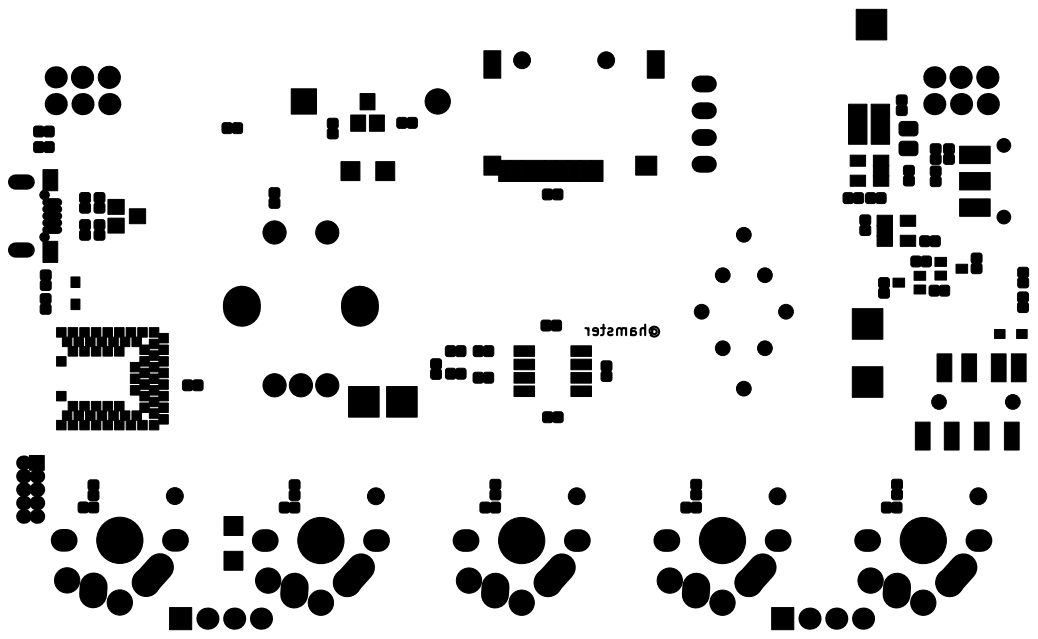
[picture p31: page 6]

File: laser-theremin.kicad_pcb Sheet: @hamster

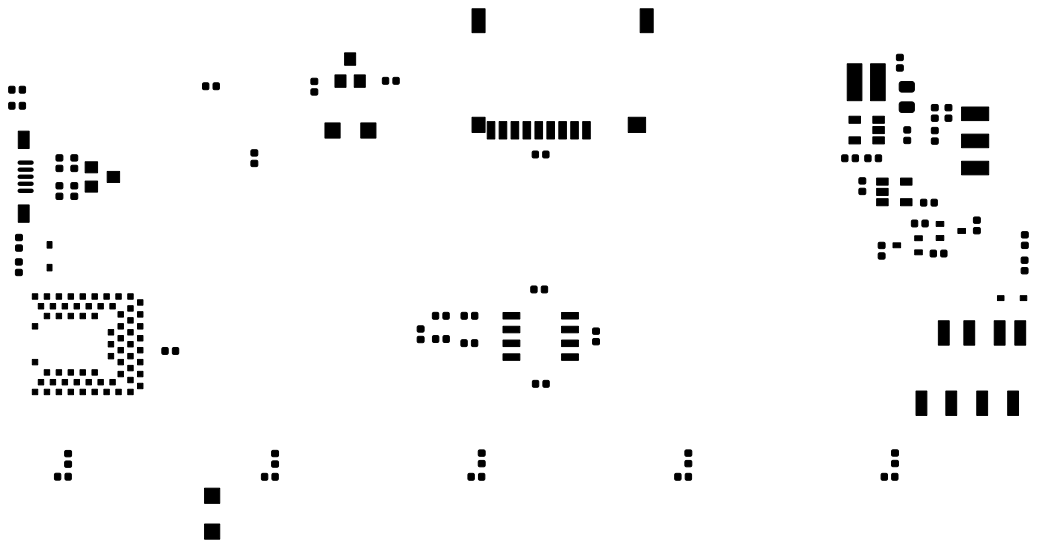
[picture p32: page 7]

File: laser-theremin.kicad_pcb Sheet:
Id: 1/1 Title:

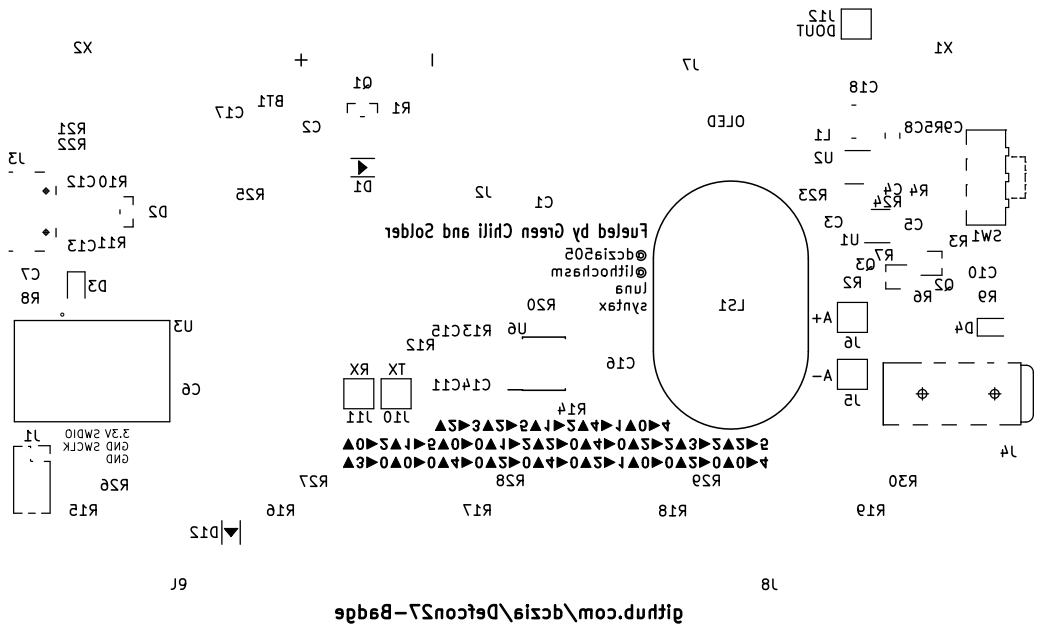
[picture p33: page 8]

File: laser-theremin.kicad_pcb Sheet:
Id: 1/1 Title:

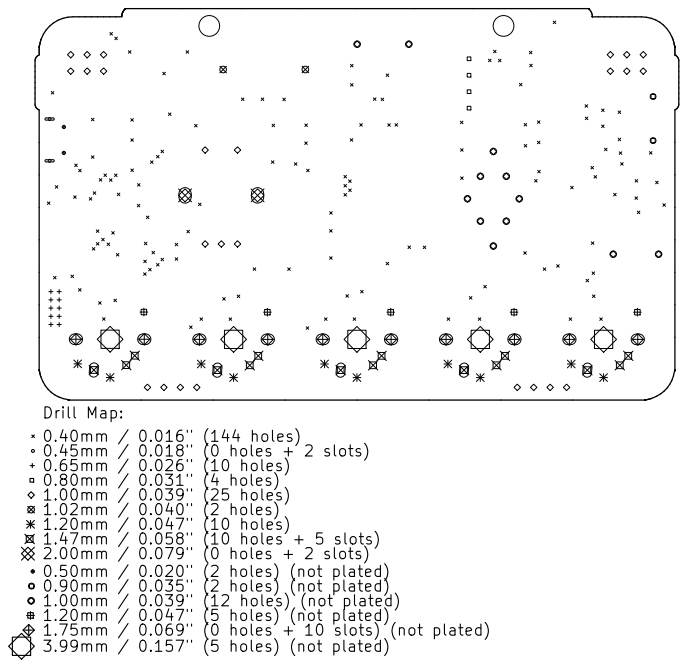
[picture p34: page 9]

Drill Map:
0.40mm / 0.016" (144 holes)
0.45mm / 0.018" (0 holes + 2 slots)
0.65mm / 0.026" (10 holes)
0.80mm / 0.031" (4 holes)
1.00mm / 0.039" (25 holes)
1.02mm / 0.040" (2 holes)
1.20mm / 0.047" (10 holes)
1.47mm / 0.058" (10 holes + 5 slots)
2.00mm / 0.079" (0 holes + 2 slots)
0.50mm / 0.020" (2 holes) (not plated)
0.90mm / 0.035" (2 holes) (not plated)
1.00mm / 0.039" (12 holes) (not plated)
1.20mm / 0.047" (5 holes) (not plated)
1.75mm / 0.069" (0 holes + 10 slots) (not plated)
3.99mm / 0.157" (5 holes) (not plated)

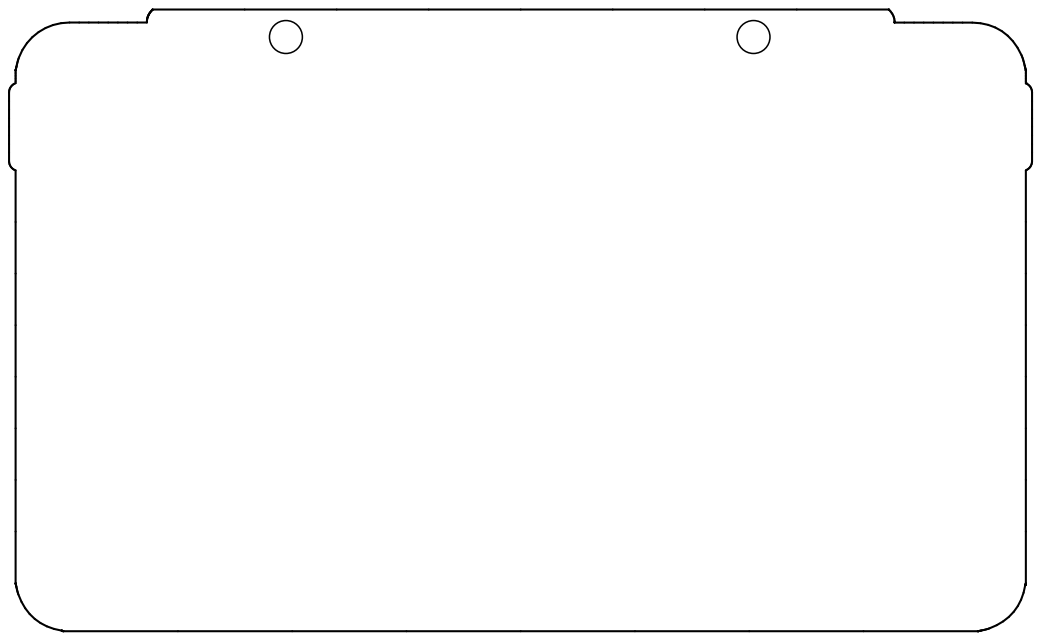
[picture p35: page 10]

File: laser-theremin.kicad_pcb Sheet:
Id: 1/1 Title:

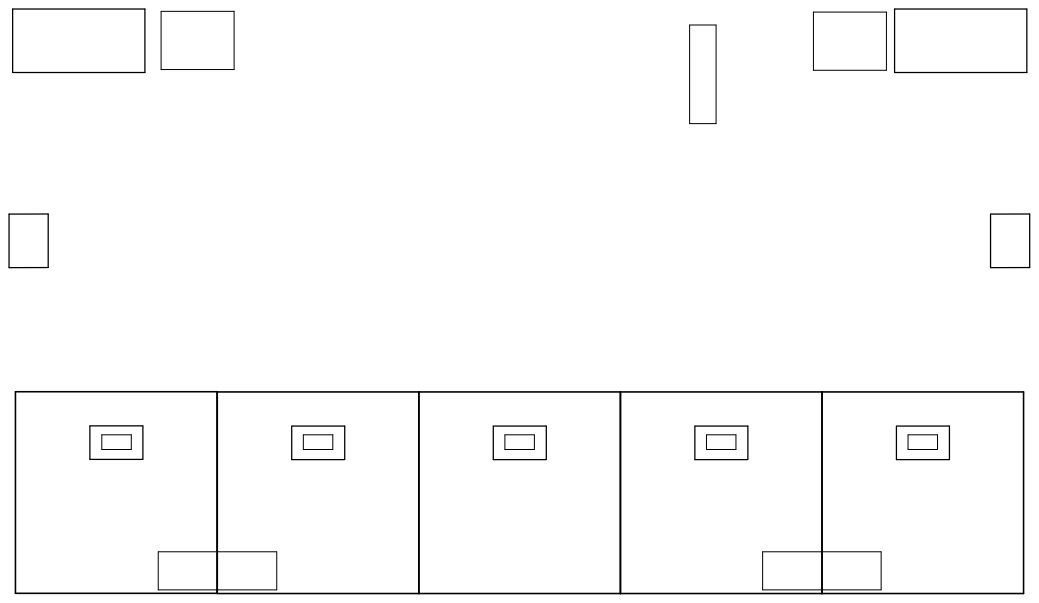
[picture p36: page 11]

File: laser-theremin.kicad_pcb Sheet:
Id: 1/1 Title:

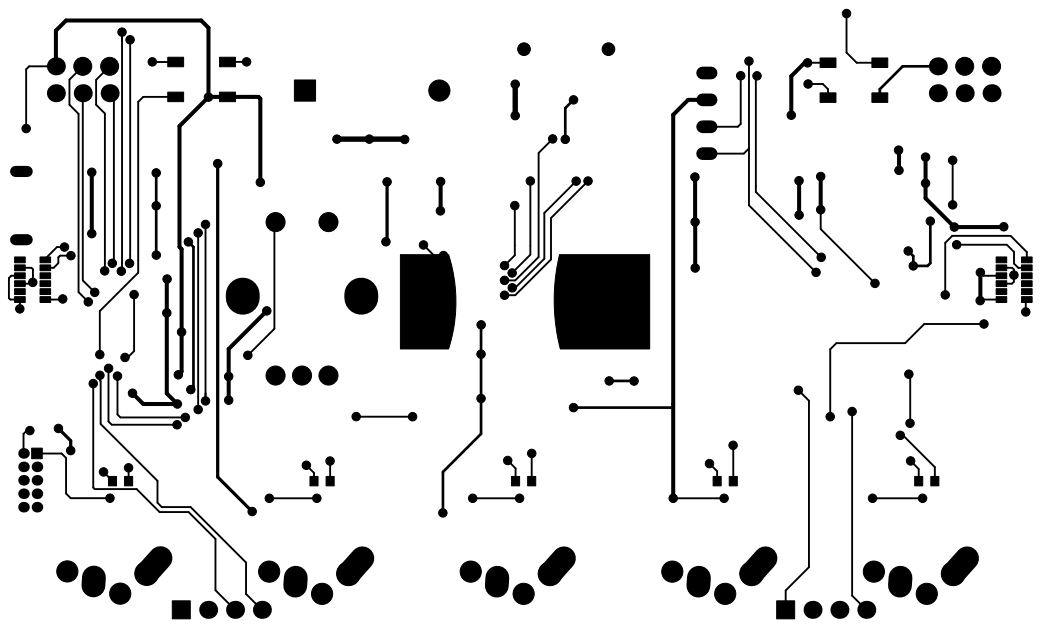
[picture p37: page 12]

File: laser-theremin.kicad_pcb Sheet:
Id: 1/1 Title:


File: laser-theremin.kicad_pcb Sheet:
Id: 1/1 Title:


File: laser-theremin.kicad_pcb Sheet:
Id: 1/1 Title:


File: laser-theremin.kicad_pcb Sheet:
Id: 1/1 Title:


File: laser-theremin.kicad_pcb Sheet:
Id: 1/1 Title:

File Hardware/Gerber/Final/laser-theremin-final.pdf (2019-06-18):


2 EN 3 VOUT/FB 4 SW 5 U2 PAM2305DABADJ

5 P1.11 54 GND1 55 TRACEDATA[0]/SW0/P1.00 56 P1.14 63 P1.15 64 P0.28 9 P0.29 10 P0.30 11 P0.31 12 Vcc 17 P0.19 37 P0.20 38 P0.18 39 P0.22 40 P0.23 41 P0.24 42 SWCLK 43 P1.05 48 P1.06 49 P1.07 50 P1.08 51 TRACEDATA[3]/P1.09 52 P1.10 53 P1.01 57 P1.02 58 P1.03 59 P0.25 6 P1.04 60 P1.12 61 P1.13 62 Vcch1 65 Vbus 66 USB_D- 67 USB_D+ 68 P0.26 7 P0.27 8 U3 BMD-340 VBUS GND

File: laser-theremin.sch Sheet: / DCZia GND MISO0 VBAT_SENSE

laser-theremin-audio.sch AUDIO_SHTDN

Id: 1/3 Title: DCZia Badge - Defcon 27


File: laser-theremin-led.sch Sheet: /LED Driver/ DC801 GND GND

3 DOUT 4 D5SK6812 DIN DOUT VSS RGB 1 DIN 2 VDD

Id: 2/3 Title: HCRN - DC801 Defcon 27 Badge


leads, soldered to pads AUDIO_SHTDN

Note: Speaker is flying

Id: 3/3 Title: File: laser-theremin-audio.sch Sheet: /mediumrehr Audio/


File: laser-theremin.kicad_pcb Sheet:
Id: 1/1 Title:


File: laser-theremin.kicad_pcb Sheet:
Id: 1/1 Title:


File: laser-theremin.kicad_pcb Sheet:
Id: 1/1 Title:


File: laser-theremin.kicad_pcb Sheet:
Id: 1/1 Title:


File: laser-theremin.kicad_pcb Sheet:
Id: 1/1 Title:


File: laser-theremin.kicad_pcb Sheet:
Id: 1/1 Title:


Drill Map:
0.40mm / 0.016" (173 holes)
0.45mm / 0.018" (0 holes + 2 slots)
0.65mm / 0.026" (10 holes)
0.80mm / 0.031" (4 holes)
1.00mm / 0.039" (25 holes)
1.02mm / 0.040" (2 holes)
1.20mm / 0.047" (10 holes)
1.47mm / 0.058" (10 holes + 5 slots)
2.00mm / 0.079" (0 holes + 2 slots)
0.50mm / 0.020" (2 holes) (not plated)
0.90mm / 0.035" (2 holes) (not plated)
0.99mm / 0.039" (2 holes) (not plated)
0.99mm / 0.039" (1 hole) (not plated)
1.00mm / 0.039" (4 holes) (not plated)
1.20mm / 0.047" (5 holes) (not plated)
1.50mm / 0.059" (27 holes) (not plated)
1.75mm / 0.069" (0 holes + 10 slots) (not plated)
3.99mm / 0.157" (5 holes) (not plated)


File: laser-theremin.kicad_pcb Sheet:
Id: 1/1 Title:


File: laser-theremin.kicad_pcb Sheet:
Id: 1/1 Title:


File: laser-theremin.kicad_pcb Sheet:
Id: 1/1 Title:


File: laser-theremin.kicad_pcb Sheet:
Id: 1/1 Title:


File: laser-theremin.kicad_pcb Sheet:
Id: 1/1 Title:


File: laser-theremin.kicad_pcb Sheet:
Id: 1/1 Title:


File: laser-theremin.kicad_pcb Sheet:
Id: 1/1 Title:

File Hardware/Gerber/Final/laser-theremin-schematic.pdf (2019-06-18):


2 EN 3 VOUT/FB 4 SW 5 U2 PAM2305DABADJ

5 P1.11 54 GND1 55 TRACEDATA[0]/SW0/P1.00 56 P1.14 63 P1.15 64 P0.28 9 P0.29 10 P0.30 11 P0.31 12 Vcc 17 P0.19 37 P0.20 38 P0.18 39 P0.22 40 P0.23 41 P0.24 42 SWCLK 43 P1.05 48 P1.06 49 P1.07 50 P1.08 51 TRACEDATA[3]/P1.09 52 P1.10 53 P1.01 57 P1.02 58 P1.03 59 P0.25 6 P1.04 60 P1.12 61 P1.13 62 Vcch1 65 Vbus 66 USB_D- 67 USB_D+ 68 P0.26 7 P0.27 8 U3 BMD-340 VBUS GND

File: laser-theremin.sch Sheet: / DCZia GND MISO0 VBAT_SENSE

laser-theremin-audio.sch AUDIO_SHTDN

Id: 1/3 Title: DCZia Badge - Defcon 27


File: laser-theremin-led.sch Sheet: /LED Driver/ DC801 GND GND

3 DOUT 4 D5SK6812 DIN DOUT VSS RGB 1 DIN 2 VDD

Id: 2/3 Title: HCRN - DC801 Defcon 27 Badge


leads, soldered to pads AUDIO_SHTDN

Note: Speaker is flying

Id: 3/3 Title: File: laser-theremin-audio.sch Sheet: /mediumrehr Audio/

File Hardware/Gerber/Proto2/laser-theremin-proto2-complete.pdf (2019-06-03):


2 EN 3 VOUT/FB 4 SW 5 U2 PAM2305DABADJ

5 P1.11 54 GND1 55 TRACEDATA[0]/SW0/P1.00 56 P1.14 63 P1.15 64 P0.28 9 P0.29 10 P0.30 11 P0.31 12 Vcc 17 P0.19 37 P0.20 38 P0.18 39 P0.22 40 P0.23 41 P0.24 42 SWCLK 43 P1.05 48 P1.06 49 P1.07 50 P1.08 51 TRACEDATA[3]/P1.09 52 P1.10 53 P1.01 57 P1.02 58 P1.03 59 P0.25 6 P1.04 60 P1.12 61 P1.13 62 Vcch1 65 Vbus 66 USB_D- 67 USB_D+ 68 P0.26 7 P0.27 8 U3 BMD-340 VBUS GND

File: laser-theremin.sch Sheet: / DCZia GND MISO0 VBAT_SENSE

laser-theremin-audio.sch AUDIO_SHTDN

Id: 1/3 Title: DCZia Badge - Defcon 27


File: laser-theremin-led.sch Sheet: /LED Driver/ DC801 GND GND

3 DOUT 4 D5SK6812 DIN DOUT VSS RGB 1 DIN 2 VDD

Id: 2/3 Title: HCRN - DC801 Defcon 27 Badge


leads, soldered to pads AUDIO_SHTDN

Note: Speaker is flying

Id: 3/3 Title: File: laser-theremin-audio.sch Sheet: /mediumrehr Audio/


File: laser-theremin.kicad_pcb Sheet:
Id: 1/1 Title:


File: laser-theremin.kicad_pcb Sheet:
Id: 1/1 Title:


File: laser-theremin.kicad_pcb Sheet:
Id: 1/1 Title:


File: laser-theremin.kicad_pcb Sheet:
Id: 1/1 Title:


File: laser-theremin.kicad_pcb Sheet:
Id: 1/1 Title:


File: laser-theremin.kicad_pcb Sheet:
Id: 1/1 Title:


Drill Map:
0.40mm / 0.016" (172 holes)
0.45mm / 0.018" (0 holes + 2 slots)
0.65mm / 0.026" (10 holes)
0.80mm / 0.031" (4 holes)
1.00mm / 0.039" (25 holes)
1.02mm / 0.040" (2 holes)
1.20mm / 0.047" (10 holes)
1.47mm / 0.058" (10 holes + 5 slots)
2.00mm / 0.079" (0 holes + 2 slots)
0.50mm / 0.020" (2 holes) (not plated)
0.90mm / 0.035" (2 holes) (not plated)
0.99mm / 0.039" (2 holes) (not plated)
0.99mm / 0.039" (1 hole) (not plated)
1.00mm / 0.039" (4 holes) (not plated)
1.20mm / 0.047" (5 holes) (not plated)
1.50mm / 0.059" (27 holes) (not plated)
1.75mm / 0.069" (0 holes + 10 slots) (not plated)
3.99mm / 0.157" (5 holes) (not plated)


File: laser-theremin.kicad_pcb Sheet:
Id: 1/1 Title:


File: laser-theremin.kicad_pcb Sheet:
Id: 1/1 Title:


File: laser-theremin.kicad_pcb Sheet:
Id: 1/1 Title:


File: laser-theremin.kicad_pcb Sheet:
Id: 1/1 Title:


File: laser-theremin.kicad_pcb Sheet:
Id: 1/1 Title:


File: laser-theremin.kicad_pcb Sheet:
Id: 1/1 Title:


File: laser-theremin.kicad_pcb Sheet:
Id: 1/1 Title:



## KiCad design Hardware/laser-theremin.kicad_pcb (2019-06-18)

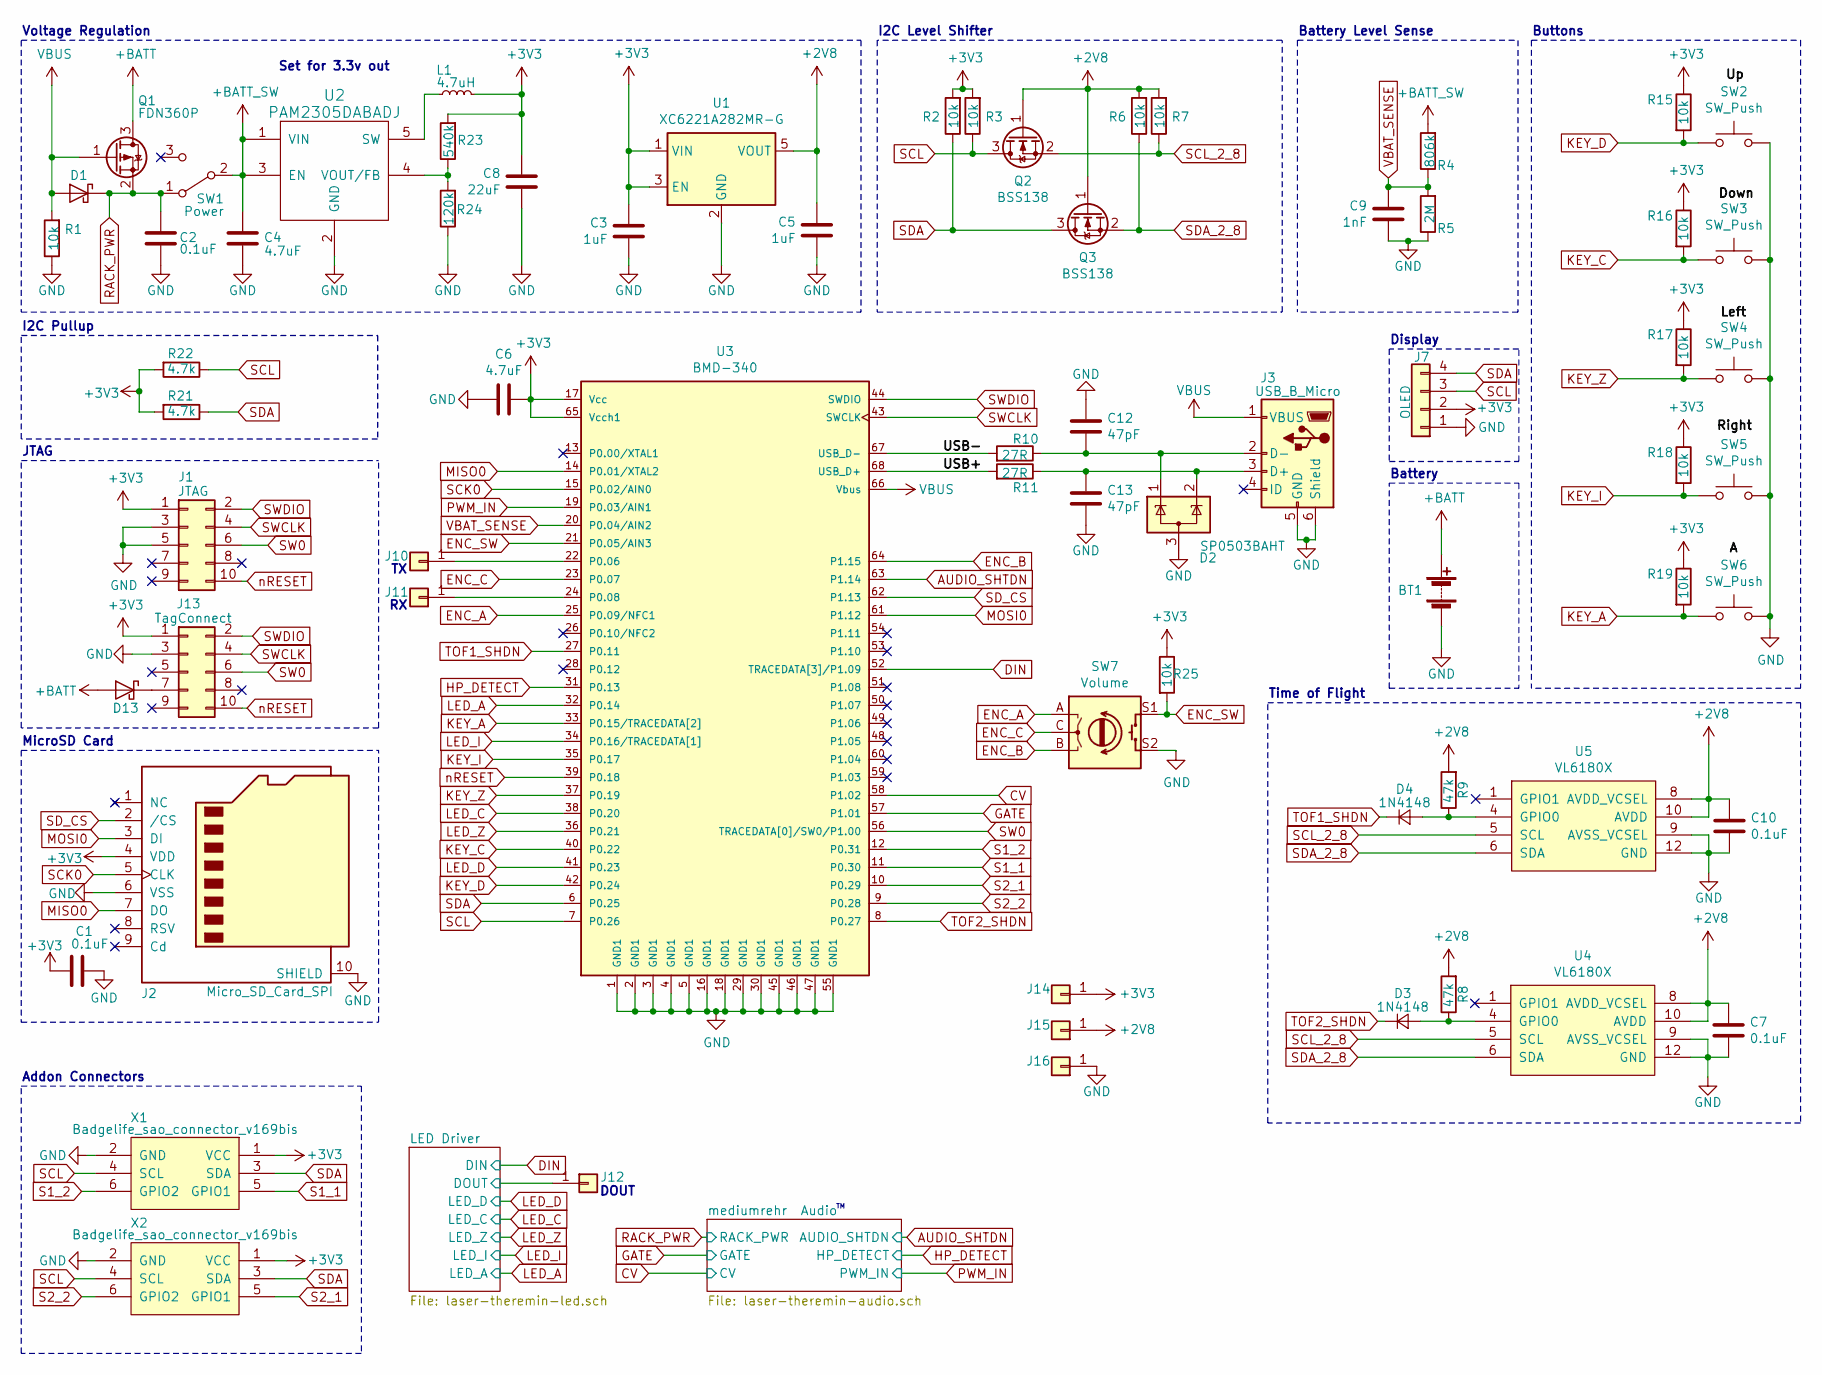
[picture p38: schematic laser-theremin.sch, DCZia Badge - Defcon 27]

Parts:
BT1: Battery; BatteryHolder_Keystone_2479_3xAAA-NoDrill
C1, C2, C7, C10: 0.1uF; C_0402_1005Metric
C3, C5: 1uF; C_0402_1005Metric
C4, C6: 4.7uF; C_0402_1005Metric
C8: 22uF; C_0805_2012Metric
C9: 1nF; C_0402_1005Metric
C12, C13: 47pF; C_0402_1005Metric
D1, D13: D_Schottky; SOD-123
D2: SP0503BAHT; SOT-23
D3, D4: 1N4148; D_SOD-323_HandSoldering
J1: JTAG; PinHeader_2x05_P1.27mm_Vertical_Sneaky
J2: Micro_SD_Card_SPI; MicroSD-Socket-Seeed-320090008
J3: USB_B_Micro; MICRO-USB5+4P-SMD-0.65-B
J7: OLED
J10, J11, J14, J15, J16: Conn_01x01; TestPoint_Pad_2.5x2.5mm
J12: Conn_01x01; TestPoint_Pad_1.0x1.0mm
J13: TagConnect; TC2050-NL_SMALL
L1: 4.7uH; L_Wuerth_MAPI-3020
Q1: FDN360P; SOT-23
Q2, Q3: BSS138; SOT-323_SC-70
R1, R2, R3, R6, R7, R15, R16, R17, R18, R19, R25: 10k; R_0402_1005Metric
R4: 806k; R_0402_1005Metric
R5: 2M; R_0402_1005Metric
R8, R9: 47k; R_0402_1005Metric
R10, R11: 27R; R_0402_1005Metric
R21, R22: 4.7k; R_0402_1005Metric
R23: 540k; R_0402_1005Metric
R24: 120k; R_0402_1005Metric
SW1: Power; SW_SPDT_CK-JS102011SAQN
SW2, SW3, SW4, SW5, SW6: SW_Push; MX-Alps-Choc-1U
SW7: Volume; RotaryEncoder
U1: XC6221A282MR-G; SOT-23-5
U2: PAM2305DABADJ; SOT-23-5
U3: BMD-340; RIGADO_BMD-340
U4, U5: VL6180X
X1, X2: Badgelife_sao_connector_v169bis; Badgelife-Shitty-v1.69bis

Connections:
+2V8: C5.1, C7.1, C10.1, J15.1, Q2.1 (G), Q3.1 (G), R6.2, R7.2, R8.2, R9.2, U1.5 (VOUT), U4.8 (AVDD_VCSEL), U4.10 (AVDD), U5.8 (AVDD_VCSEL), U5.10 (AVDD)
+BATT: BT1.1 (+), D13.2 (A), Q1.3 (D)
+BATT_SW: C4.1, R4.2, SW1.2 (B), U2.1 (VIN), U2.3 (EN)
/LED Driver/DOUT: J12.1; also elsewhere on the board
/USB+: R11.2, U3.68 (USB_D+)
/USB-: R10.2, U3.67 (USB_D-)
AUDIO_SHTDN: U3.63 (P1.14); also elsewhere on the board
CV: U3.58 (P1.02); also elsewhere on the board
DIN: U3.52 (TRACEDATA[3]/P1.09); also elsewhere on the board
ENC_A: SW7.A, U3.25 (P0.09/NFC1)
ENC_B: SW7.B, U3.64 (P1.15)
ENC_C: SW7.C, U3.23 (P0.07)
ENC_SW: R25.2, SW7.S1, U3.21 (P0.05/AIN3)
GATE: U3.57 (P1.01); also elsewhere on the board
GND: BT1.2 (-), C1.1, C2.2, C3.2, C4.2, C5.2, C6.2, C7.2, C8.2, C9.2, C10.2, C12.1, C13.2, D2.3 (A), J1.3, J1.5, J2.6 (VSS), J2.10 (SHIELD), J3.5 (GND), J3.6 (Shield), J7.1, J13.3, J16.1, R1.1, R5.1, R24.1, SW2.2, SW3.2, SW4.2, SW5.2, SW6.2, SW7.S2, U1.2 (GND), U2.2 (GND), U3.1 (GND1), U3.2 (GND1), U3.3 (GND1), U3.4 (GND1), U3.5 (GND1), U3.16 (GND1), U3.18 (GND1), U3.29 (GND1), U3.30 (GND1), U3.45 (GND1), U3.46 (GND1), U3.47 (GND1), U3.55 (GND1), U4.9 (AVSS_VCSEL), U4.12 (GND), U5.9 (AVSS_VCSEL), U5.12 (GND), X1.2 (GND), X2.2 (GND); also elsewhere on the board
HP_DETECT: U3.31 (P0.13); also elsewhere on the board
KEY_A: R19.2, SW6.1, U3.33 (P0.15/TRACEDATA[2])
KEY_C: R16.2, SW3.1, U3.40 (P0.22)
KEY_D: R15.2, SW2.1, U3.42 (P0.24)
KEY_I: R18.2, SW5.1, U3.35 (P0.17)
KEY_Z: R17.2, SW4.1, U3.37 (P0.19)
LED_A: U3.32 (P0.14); also elsewhere on the board
LED_C: U3.38 (P0.20); also elsewhere on the board
LED_D: U3.41 (P0.23); also elsewhere on the board
LED_I: U3.34 (P0.16/TRACEDATA[1]); also elsewhere on the board
LED_Z: U3.36 (P0.21); also elsewhere on the board
MISO0: J2.7 (DO), U3.14 (P0.01/XTAL2)
MOSI0: J2.3 (DI), U3.61 (P1.12)
unnamed: C12.2, D2.1 (K), J3.2 (D-), R10.1
unnamed: C13.1, D2.2 (K), J3.3 (D+), R11.1
unnamed: D3.2 (A), R8.1, U4.4 (GPIO0)
unnamed: D4.2 (A), R9.1, U5.4 (GPIO0)
unnamed: D13.1 (K), J13.7
unnamed: J10.1, U3.22 (P0.06)
unnamed: J11.1, U3.24 (P0.08)
unnamed: L1.1, U2.5 (SW)
unnamed: R23.1, R24.2, U2.4 (VOUT/FB)
PWM_IN: U3.19 (P0.03/AIN1); also elsewhere on the board
RACK_PWR: C2.1, D1.1 (K), Q1.2 (S), SW1.1 (A); also elsewhere on the board
S1_1: U3.11 (P0.30), X1.5 (GPIO1)
S1_2: U3.12 (P0.31), X1.6 (GPIO2)
S2_1: U3.10 (P0.29), X2.5 (GPIO1)
S2_2: U3.9 (P0.28), X2.6 (GPIO2)
SCK0: J2.5 (CLK), U3.15 (P0.02/AIN0)
SCL: J7.3, Q2.3 (D), R3.1, R22.1, U3.7 (P0.26), X1.4 (SCL), X2.4 (SCL)
SCL_2_8: Q2.2 (S), R7.1, U4.5 (SCL), U5.5 (SCL)
SDA: J7.4, Q3.3 (D), R2.1, R21.1, U3.6 (P0.25), X1.3 (SDA), X2.3 (SDA)
SDA_2_8: Q3.2 (S), R6.1, U4.6 (SDA), U5.6 (SDA)
SD_CS: J2.2 (/CS), U3.62 (P1.13)
SW0: J1.6, J13.6, U3.56 (TRACEDATA[0]/SW0/P1.00)
SWCLK: J1.4, J13.4, U3.43 (SWCLK)
SWDIO: J1.2, J13.2, U3.44 (SWDIO)
TOF1_SHDN: D4.1 (K), U3.27 (P0.11)
TOF2_SHDN: D3.1 (K), U3.8 (P0.27)
VBAT_SENSE: C9.1, R4.1, R5.2, U3.20 (P0.04/AIN2)
VBUS: D1.2 (A), J3.1 (VBUS), Q1.1 (G), R1.2, U3.66 (Vbus)
nRESET: J1.10, J13.10, U3.39 (P0.18)

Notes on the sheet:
Buttons
Voltage Regulation
MicroSD Card
Battery Level Sense
Addon Connectors
JTAG
Battery
Set for 3.3v out
I2C Level Shifter
Time of Flight
I2C Pullup
Display
DOUT

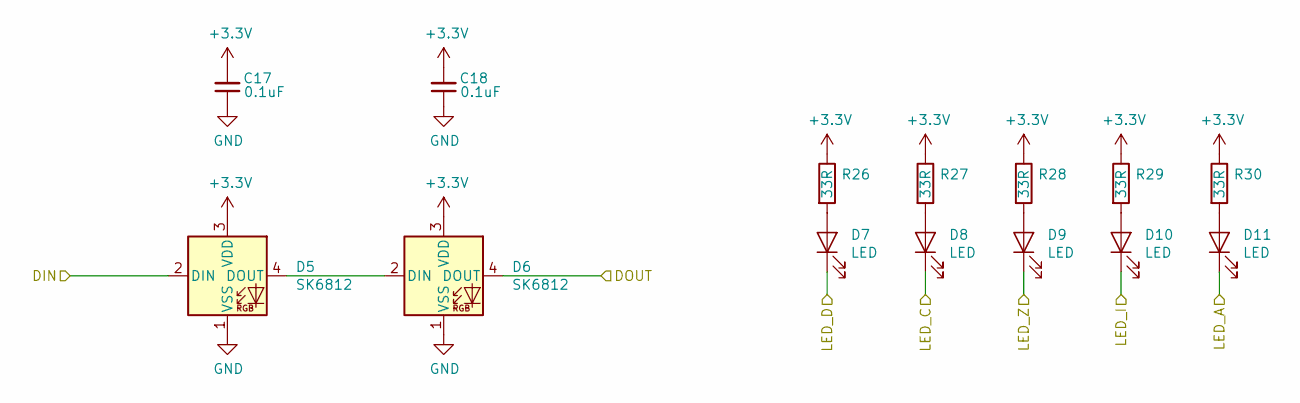
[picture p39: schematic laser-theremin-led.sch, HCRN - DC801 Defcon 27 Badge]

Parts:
C17, C18: 0.1uF; C_0402_1005Metric
D5, D6: SK6812; LED4-SMD-5050
D7, D8, D9, D10, D11: LED; LED-0603
R26, R27, R28, R29, R30: 33R; R_0402_1005Metric

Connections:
/LED Driver/DOUT: D6.4 (DOUT); also elsewhere on the board
DIN: D5.2 (DIN); also elsewhere on the board
GND: C17.1, C18.1, D5.1 (VSS), D6.1 (VSS); also elsewhere on the board
LED_A: D11.1 (K); also elsewhere on the board
LED_C: D8.1 (K); also elsewhere on the board
LED_D: D7.1 (K); also elsewhere on the board
LED_I: D10.1 (K); also elsewhere on the board
LED_Z: D9.1 (K); also elsewhere on the board
unnamed: D5.4 (DOUT), D6.2 (DIN)
unnamed: D7.2 (A), R26.2
unnamed: D8.2 (A), R27.2
unnamed: D9.2 (A), R28.2
unnamed: D10.2 (A), R29.2
unnamed: D11.2 (A), R30.2

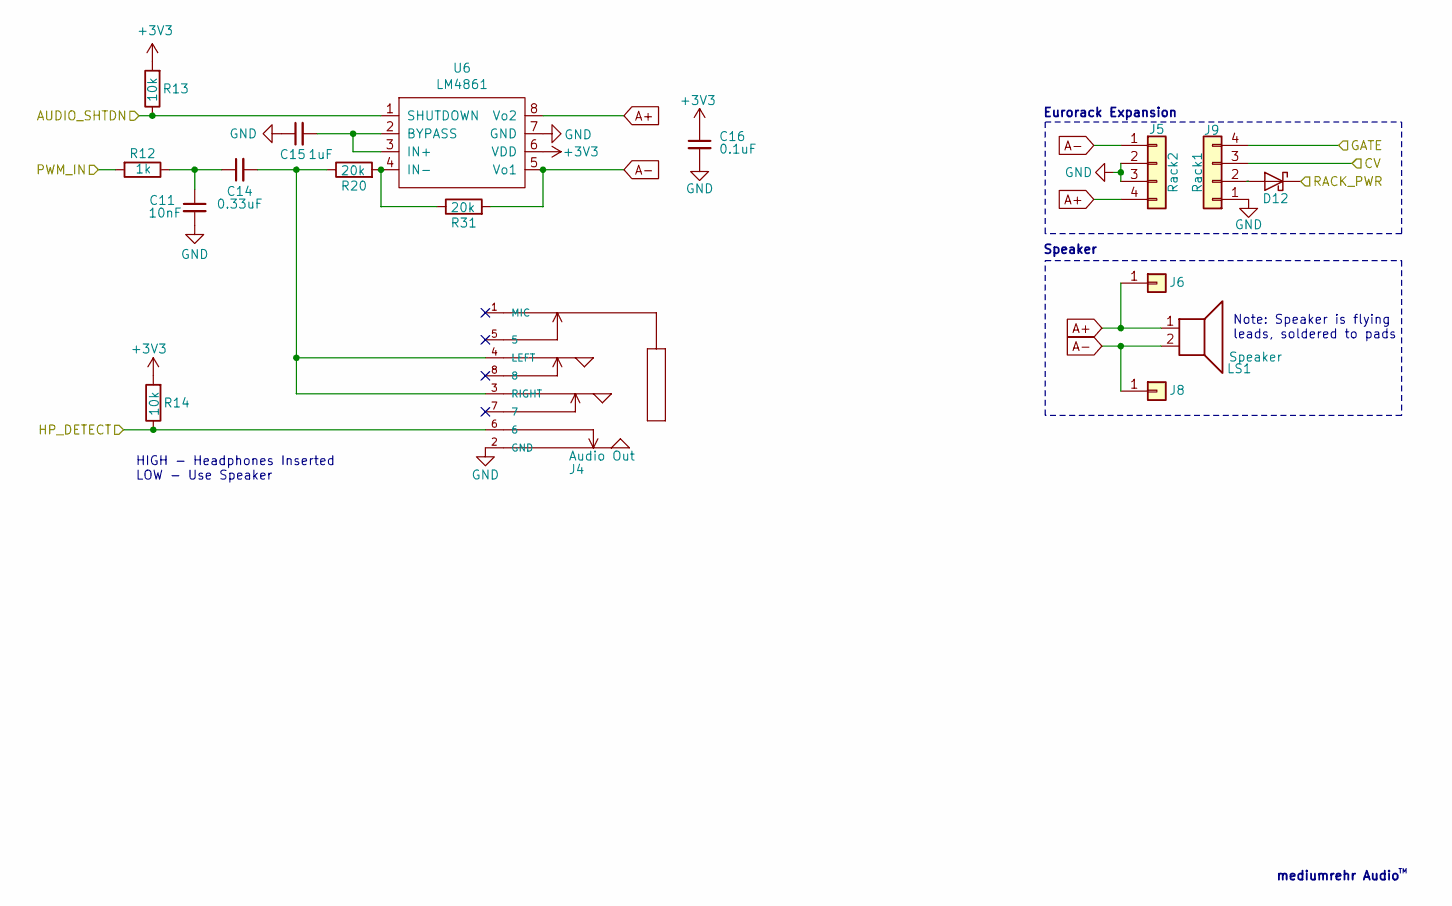
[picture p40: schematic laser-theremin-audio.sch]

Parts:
C11: 10nF; C_0402_1005Metric
C14: 0.33uF; C_0402_1005Metric
C15: 1uF; C_0402_1005Metric
C16: 0.1uF; C_0402_1005Metric
D12: D_Schottky; SOD-123
J4: Audio Out; AUDIO8P-SMD-3.5-14.5X6X5MM
J5: Rack2; PinHeader_1x04_P2.54mm_Vertical
J6, J8: Conn_01x01; TestPoint_Pad_2.5x2.5mm
J9: Rack1; PinHeader_1x04_P2.54mm_Vertical
LS1: Speaker
R12: 1k; R_0402_1005Metric
R13, R14: 10k; R_0402_1005Metric
R20, R31: 20k; R_0402_1005Metric
U6: LM4861; SOIC-8_3.9x4.9mm_P1.27mm

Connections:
A+: J5.4, J6.1, LS1.1, U6.8 (Vo2)
A-: J5.1, J8.1, LS1.2, R31.2, U6.5 (Vo1)
AUDIO_SHTDN: R13.1, U6.1 (SHUTDOWN); also elsewhere on the board
CV: J9.3; also elsewhere on the board
GATE: J9.4; also elsewhere on the board
GND: C11.2, C15.1, C16.2, J4.2 (GND), J5.2, J5.3, J9.1, U6.7 (GND); also elsewhere on the board
HP_DETECT: J4.6, R14.1; also elsewhere on the board
unnamed: C11.1, C14.1, R12.1
unnamed: C14.2, J4.3 (RIGHT), J4.4 (LEFT), R20.1
unnamed: C15.2, U6.2 (BYPASS), U6.3 (IN+)
unnamed: D12.2 (A), J9.2
unnamed: R20.2, R31.1, U6.4 (IN-)
PWM_IN: R12.2; also elsewhere on the board
RACK_PWR: D12.1 (K); also elsewhere on the board

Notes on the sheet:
mediumrehr Audio
Eurorack Expansion
Speaker
Note: Speaker is flying leads, soldered to pads
HIGH - Headphones Inserted LOW - Use Speaker

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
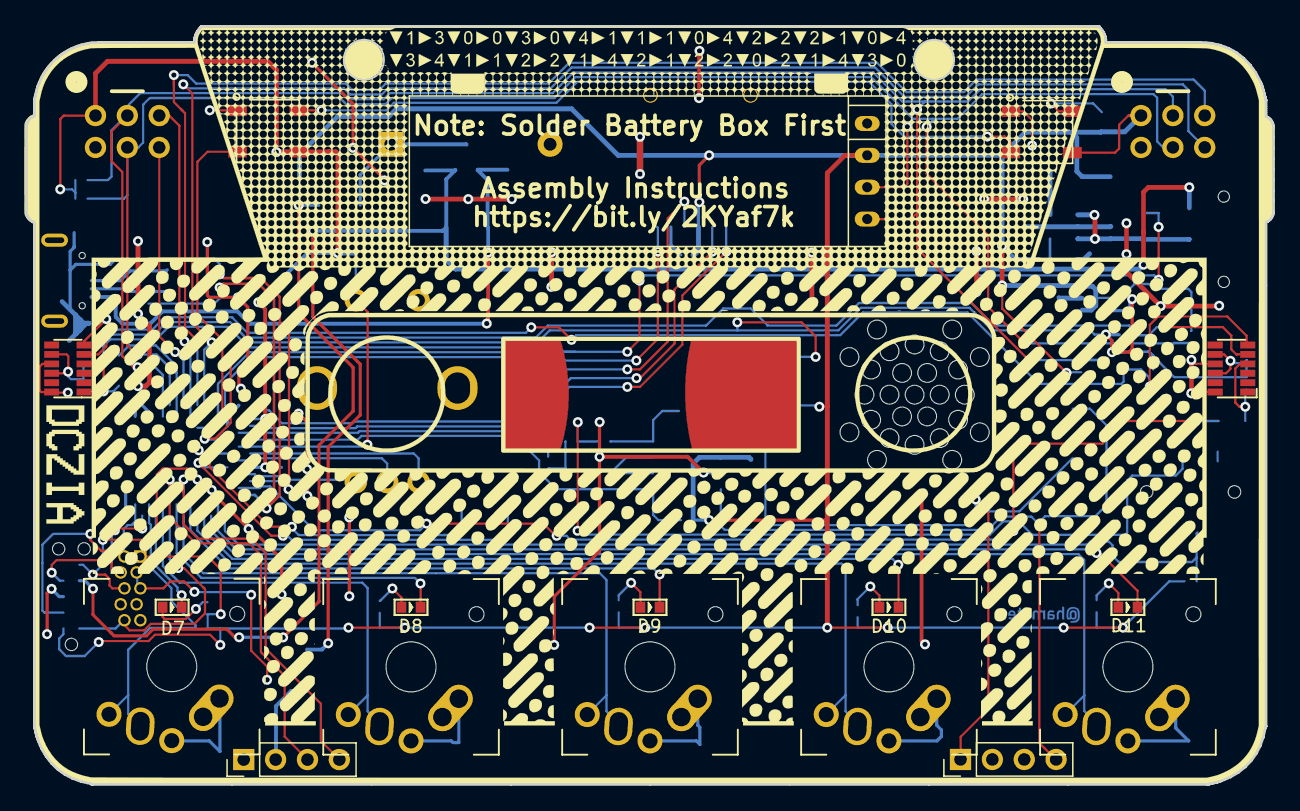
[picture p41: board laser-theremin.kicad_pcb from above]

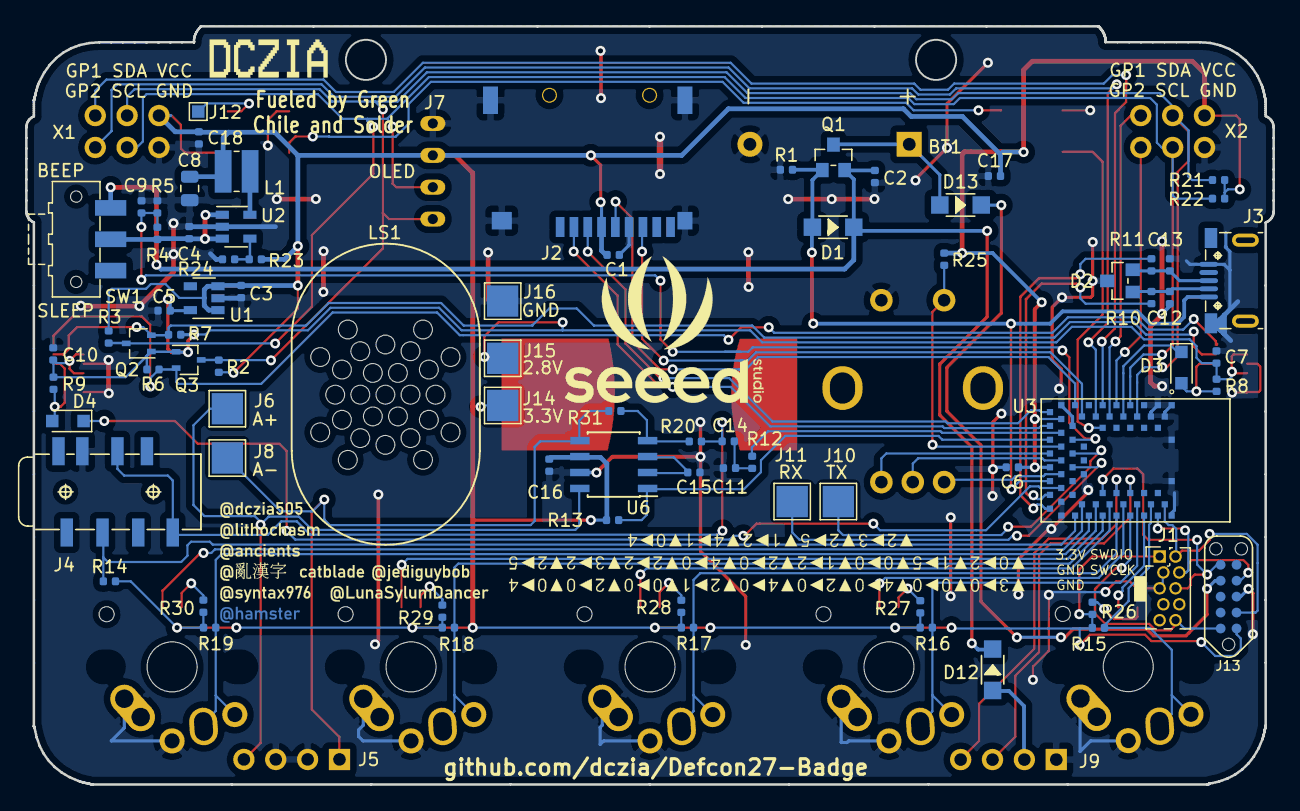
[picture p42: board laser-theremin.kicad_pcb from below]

Board: 2 copper layers, 99.4 x 60.4 mm, 99 parts (79 on the bottom side), 71 nets.

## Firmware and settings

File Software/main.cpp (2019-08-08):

 /**
 *
 * @file main.c
 *
 * @date August 2, 2019
 * @author hamster, rehr, ancients, lithochasm
 *
 * @brief This is the entry point for the DCZia DC27 Theremin badge
 *
 */

#include "./main.h"
uint8_t badgeMode;

ADC *adc;
VL6180X *TOF;
Audio *audio;
LED *leds;
WS2812S *pixels;
SAO *theremini;

// Variables for LED modes
bool led_status = false;
bool cylonGoDown = false;
int cylonCurLED = LED_D;
int led_mode = 1;
uint16_t led_speed;
int led_pattern_step = 1;
int led_pattern2_step = 1;
uint8_t output1;
uint8_t output2;

// Audio Variables
uint8_t octave = 6;
uint8_t octavesUp = 0;

/**
 * Initialize the button pins
 */
static void button_init() {
    DButtonPressed = false;
    CButtonPressed = false;
    ZButtonPressed = false;
    IButtonPressed = false;
    AButtonPressed = false;
    encSwPressed = false;

    /* set encoder pin directions and states */
    nrf_gpio_cfg_input(BUTTON_D_PIN, NRF_GPIO_PIN_NOPULL);
    nrf_gpio_cfg_input(BUTTON_C_PIN, NRF_GPIO_PIN_NOPULL);
    nrf_gpio_cfg_input(BUTTON_Z_PIN, NRF_GPIO_PIN_NOPULL);
    nrf_gpio_cfg_input(BUTTON_I_PIN, NRF_GPIO_PIN_NOPULL);
    nrf_gpio_cfg_input(BUTTON_A_PIN, NRF_GPIO_PIN_NOPULL);
    nrf_gpio_cfg_input(ENC_SW_PIN, NRF_GPIO_PIN_NOPULL);

    /* initialize interrupt driver */
    if (nrfx_gpiote_is_init() == false) {
        if (nrf_drv_gpiote_init() != NRF_SUCCESS) {
            printf("ERROR: Initializing button interrupts!\n");
            return;
        }
    }

    /* set config for button pin interrupt */
    nrf_drv_gpiote_in_config_t pin_config = {
        NRF_GPIOTE_POLARITY_TOGGLE,  // sense
        NRF_GPIO_PIN_NOPULL,  // pull
        true,  // is_watcher
        true  // hi_accuracy
    };

    /* init and enable encoder pin A interrupt */
    nrf_drv_gpiote_in_init(BUTTON_D_PIN, &pin_config, button_handler);
    nrf_drv_gpiote_in_init(BUTTON_C_PIN, &pin_config, button_handler);
    nrf_drv_gpiote_in_init(BUTTON_Z_PIN, &pin_config, button_handler);
    nrf_drv_gpiote_in_init(BUTTON_I_PIN, &pin_config, button_handler);
    nrf_drv_gpiote_in_init(BUTTON_A_PIN, &pin_config, button_handler);
    nrf_drv_gpiote_in_init(ENC_SW_PIN, &pin_config, button_handler);
    nrf_drv_gpiote_in_event_enable(BUTTON_D_PIN, true);
    nrf_drv_gpiote_in_event_enable(BUTTON_C_PIN, true);
    nrf_drv_gpiote_in_event_enable(BUTTON_Z_PIN, true);
    nrf_drv_gpiote_in_event_enable(BUTTON_I_PIN, true);
    nrf_drv_gpiote_in_event_enable(BUTTON_A_PIN, true);
    nrf_drv_gpiote_in_event_enable(ENC_SW_PIN, true);
}


/**
 * Handler for encoder pin A change events
 */
void encoder_handler(nrf_drv_gpiote_pin_t pin, nrf_gpiote_polarity_t action) {
    static bool prevPinAState = false;

    if (pin == ENC_A_PIN) {
        // grab states for pins A and B
        bool pinBState = nrfx_gpiote_in_is_set(ENC_B_PIN);
        bool pinAState = nrfx_gpiote_in_is_set(ENC_A_PIN);

        // double check for a change on pin A
        if (prevPinAState != pinAState) {
            if (prevPinAState == false) {
                if (pinBState) {
                    // counter-clockwise turn
                    if (--octave < 1) {
                        octave = 1;
                    }
                } else {
                    // clockwise turn
                    if (++octave > 6) {
                        octave = 6; // as of right now, timer freaks if you go into octave C8
                    }
                }
            }

            prevPinAState = pinAState;
        }
    }
}


/**
 * Initialize the encoder pins
 */
static void encoder_init() {
    /* set encoder pin directions and states */
    nrf_gpio_cfg_output(ENC_C_PIN);
    nrf_gpio_pin_clear(ENC_C_PIN);  // set pin C as 0V
    nrf_gpio_cfg_input(ENC_A_PIN, NRF_GPIO_PIN_PULLUP);
    nrf_gpio_cfg_input(ENC_B_PIN, NRF_GPIO_PIN_PULLUP);

    /* initialize interrupt driver */
    if (nrfx_gpiote_is_init() == false) {
        if (nrf_drv_gpiote_init() != NRF_SUCCESS) {
            printf("ERROR: Initializing encoder interrupts!\n");
            return;
        }
    }

    /* set config for encoder pin A interrupt */
    nrf_drv_gpiote_in_config_t pin_config = {
        NRF_GPIOTE_POLARITY_TOGGLE,  // sense
        NRF_GPIO_PIN_PULLUP,  // pull
        true,  // is_watcher
        true  // hi_accuracy
    };

    /* init and enable encoder pin A interrupt */
    nrf_drv_gpiote_in_init(ENC_A_PIN, &pin_config, encoder_handler);
    nrf_drv_gpiote_in_event_enable(ENC_A_PIN, true);
}


/**
 * Initialize the logging backend for logging over JTAG
 */
static void log_init() {
    ret_code_t err_code = NRF_LOG_INIT(NULL);
    APP_ERROR_CHECK(err_code);

    NRF_LOG_DEFAULT_BACKENDS_INIT();
}

void createTimers() {
    // Create a timer in repeated mode for LEDs
    app_timer_create(&m_led_timer_id, APP_TIMER_MODE_REPEATED, led_handler_cylon);

    // Create a timer for audio node stepping
    app_timer_create(&m_audio_step_timer_id, APP_TIMER_MODE_REPEATED, audio_timer_handler);
}


/**
 * @brief Main app
 * @return Not used
 */
int main() {
    // Setup the system

    // Set up buttons
    button_init();

    // set up encoder
    encoder_init();

    log_init();

    // Timers
    app_timer_init();
    createTimers();

    // Setup I2C
    twi_master_init();

    // LEDs
    leds = new LED();

    // RGB LEDs
    pixels = new WS2812S(2);

    // Setup the audio
    audio = new Audio();

    // Play a sequence so we kill time while the SSD1306 Boots
    startup_sequence();

    // Setup the OLED display
    oled_init();

    // Setup the TOF
    TOF = new VL6180X();
    TOF->begin();

    // Setup the battery monitor
    adc = new ADC();

    // Setup SAO
    theremini = new SAO(0x23);

    // BLE
    ble_stack_init();
    scan_start();

    // Init the random number generator
    nrf_drv_rng_init(nullptr);

    // Configure the systick
    sysTickStart();
    // Setup the BLE
    advertising_setUser("-DCZia505-");
    ble_adv_start();

    // Setup TOF range variables
    uint8_t range1 = 0, range2 = 0;
    uint8_t status1 = 0, status2 = 0;

    //Looping behavior
    char display2[22];
    char display1[20];
    char voltageDisp[5];
    char octaveDisp[3];
    uint8_t voltageOnes = 0;
    uint8_t voltageDecimal = 0;

    badgeMode = BADGE_MODE_DEFAULT;

    while (true) {
        uint16_t voltage = adc->getBatteryVoltage();
        voltageOnes = voltage / 1000;
        voltageDecimal = (voltage % 1000) / 100;
        if (badgeMode == BADGE_MODE_THEREMIN) {
            /* theremin mode */
            range1 = tof_pitch(range1);
            range2 = tof_volume(range2);
            snprintf(display1, 20, " THEREMIN");
            snprintf(display2, 22, "%03dmm      C%d   %03dmm", range2, octave + octavesUp, range1);
            // snprintf(display2, 20, "%03dmm Sine %03dmm", audio->getVolume(), range1);
        } else if (badgeMode == BADGE_MODE_FIXED_VOL) {
            /* fixed volume mode */
            range1 = tof_pitch(range1);
            audio->setVolume(16);
            snprintf(display1, 20, " THEREMIN");
            snprintf(display2, 22, "fixed      C%d   %03dmm", octave + octavesUp, range1);
        } else if (badgeMode == BADGE_MODE_CREDITS) {
            /* credits mode / music playback */
            snprintf(display1, 20, " Credits...");
            snprintf(display2, 22, " Malort", range1);
            // something cool
            if (!audio->songIsPlaying()) {
                audio_off();
                audio->startSongPlayback();
                app_timer_start(m_audio_step_timer_id, APP_TIMER_TICKS(50), nullptr);
            }
        } else {
            /* default mode */
            audio_off();  // STFU <- "i feel personally attacked" - rehr
                         // No offense intended, just wanted it to boot into a quiet mode :)

            led_theramin();  // Enables LED Thearamin Mode
            snprintf(display1, 20, " LED Mode");
            if (led_mode == 1) {
                snprintf(display2, 22, " Cylon");
            } else if (led_mode == 2) {
                snprintf(display2, 22, " Chile");
            } else if (led_mode == 3) {
                snprintf(display2, 22, " Vapor");
            } else if (led_mode == 4) {
                snprintf(display2, 22, " Warp core");
            } else if (led_mode == 5) {
                snprintf(display2, 22, " Malort");
            } else {
                snprintf(display2, 22, "");
            }
        }

        snprintf(voltageDisp, 5, "%d.%dv", voltageOnes, voltageDecimal);

        SSD1306_clearDisplay();
        util_gfx_set_font(FONT_MONO55_8PT);
        util_gfx_set_cursor(0, 1);
        util_gfx_print(display1, COLOR_WHITE);
        if (!((badgeMode == BADGE_MODE_THEREMIN) || (badgeMode == BADGE_MODE_FIXED_VOL))) {
            util_gfx_set_cursor(0, 15);
            util_gfx_print(display2, COLOR_WHITE);
            util_gfx_set_font(FONT_VERAMONO_5PT);
        } else {
            util_gfx_draw_waveform(48, 21, COLOR_WHITE, audio->getWaveform());
            util_gfx_set_font(FONT_VERAMONO_5PT);
            util_gfx_set_cursor(0, 22);
            util_gfx_print(display2, COLOR_WHITE);
        }
        util_gfx_set_cursor(105, 1);
        util_gfx_print(voltageDisp, COLOR_WHITE);

        SSD1306_display();
        checkButtonHolds();

        checkSAO();

        // nrf_delay_ms(10);  // Do we really need this?
    }
}

void checkSAO(void){

    uint8_t key = 0;
    theremini->read(&key, 1);

    if(key != 0) {
        printf("Last key is %d\n", key);
        modeSet((BUTTON_PRESS)key);
    }

}

void incrementBadgeMode() {
    badgeMode++;
    if (badgeMode >= ( BADGE_MODES - 1)) {
        badgeMode = 0;
    }
}

void audio_off() {
    audio->enable(false);  // turn off amp
    audio->disableTimer();  // disable timer1
    audio->setPWM0Ch0Value(0);  // turn off PWM0 ch0
}

void modeSet(BUTTON_PRESS buttonPress){

    switch(buttonPress){
        case BUTTON_PRESS_D:
            if (badgeMode == BADGE_MODE_DEFAULT) {
                led_mode = 1;
            } else if ((badgeMode == BADGE_MODE_THEREMIN) || (badgeMode == BADGE_MODE_FIXED_VOL)) {
                audio->setWaveform(WAVE_SINE);
            }
            break;
        case BUTTON_PRESS_C:
            if (badgeMode == BADGE_MODE_DEFAULT) {
                led_mode = 2;
            } else if ((badgeMode == BADGE_MODE_THEREMIN) || (badgeMode == BADGE_MODE_FIXED_VOL)) {
                audio->setWaveform(WAVE_TRI);
            }
            break;
        case BUTTON_PRESS_Z:
            if (badgeMode == BADGE_MODE_DEFAULT) {
                led_mode = 3;
            } else if ((badgeMode == BADGE_MODE_THEREMIN) || (badgeMode == BADGE_MODE_FIXED_VOL)) {
                audio->setWaveform(WAVE_RAMP);
            }
            break;
        case BUTTON_PRESS_I:
            if (badgeMode == BADGE_MODE_DEFAULT) {
                led_mode = 4;
            } else if ((badgeMode == BADGE_MODE_THEREMIN) || (badgeMode == BADGE_MODE_FIXED_VOL)) {
                audio->setWaveform(WAVE_SQR);
            }
            break;
        case BUTTON_PRESS_A:
            if (badgeMode == BADGE_MODE_DEFAULT) {
                led_mode = 5;
            } else if ((badgeMode == BADGE_MODE_THEREMIN) || (badgeMode == BADGE_MODE_FIXED_VOL)) {
                audio->setWaveform(WAVE_NOIZ);
            }
            break;
    }

}

/**
 * Handler for encoder pin A change events
 */
void button_handler(nrf_drv_gpiote_pin_t pin, nrf_gpiote_polarity_t action) {
    nrf_delay_us(2000); // lil' debounce

    if (pin == BUTTON_D_PIN) {
        if (nrfx_gpiote_in_is_set(BUTTON_D_PIN) == false) {
            if (!DButtonPressed) {
                // add code that runs one time when button is pressed
                modeSet(BUTTON_PRESS_D);
                leds->set(LED_D, ON);
                printf("Button D Pressed\n");
                DButtonPressed = true;
            }
        } else {
            if (DButtonPressed) {
                // add code that runs one time when button is release

                leds->set(LED_D, OFF);
                printf("Button D Released\n");

                DButtonPressed = false;
            }
        }
    }

    if (pin == BUTTON_C_PIN) {
        if (nrfx_gpiote_in_is_set(BUTTON_C_PIN) == false) {
            if (!CButtonPressed) {
                // add code that runs one time when button is pressed
                modeSet(BUTTON_PRESS_C);
                leds->set(LED_C, ON);
                printf("Button C Pressed\n");

                CButtonPressed = true;
            }
        } else {
            if (CButtonPressed) {
                // add code that runs one time when button is release

                leds->set(LED_C, OFF);
                printf("Button C Released\n");

                CButtonPressed = false;
            }
        }
    }

    if (pin == BUTTON_Z_PIN) {
        if (nrfx_gpiote_in_is_set(BUTTON_Z_PIN) == false) {
            if (!ZButtonPressed) {
                // add code that runs one time when button is pressed
                modeSet(BUTTON_PRESS_Z);
                leds->set(LED_Z, ON);
                printf("Button Z Pressed\n");

                ZButtonPressed = true;
            }
        } else {
            if (ZButtonPressed) {
                // add code that runs one time when button is release

                leds->set(LED_Z, OFF);
                printf("Button Z Released\n");

                ZButtonPressed = false;
            }
        }
    }

    if (pin == BUTTON_I_PIN) {
        if (nrfx_gpiote_in_is_set(BUTTON_I_PIN) == false) {
            if (!IButtonPressed) {
                // add code that runs one time when button is pressed
                modeSet(BUTTON_PRESS_I);
                leds->set(LED_I, ON);
                printf("Button I Pressed\n");

                IButtonPressed = true;
            }
        } else {
            if (IButtonPressed) {
                // add code that runs one time when button is release

                leds->set(LED_I, OFF);
                printf("Button I Released\n");

                IButtonPressed = false;
            }
        }
    }

    if (pin == BUTTON_A_PIN) {
        if (nrfx_gpiote_in_is_set(BUTTON_A_PIN) == false) {
            if (!AButtonPressed) {
                // add code that runs one time when button is pressed
                modeSet(BUTTON_PRESS_A);
                leds->set(LED_A, ON);
                printf("Button A Pressed\n");

                AButtonPressed = true;
            }
        } else {
            if (AButtonPressed) {
                // add code that runs one time when button is release

                leds->set(LED_A, OFF);
                printf("Button A Released\n");

                AButtonPressed = false;
            }
        }
    }

    if (pin == ENC_SW_PIN) {
        if (nrfx_gpiote_in_is_set(ENC_SW_PIN)) {
            if (!encSwPressed) {
                printf("Encoder Switch Pressed\n");
                incrementBadgeMode();
                encSwPressed = true;
            }
        } else {
            if (encSwPressed) {
                printf("Encoder Switch Released\n");

                encSwPressed = false;
            }
        }
    }
}


void checkButtonHolds() {
    if (DButtonPressed && CButtonPressed && ZButtonPressed) {
        badgeMode = BADGE_MODE_CREDITS;
    }
}


void startup_sequence() {
    audio->enable(true);
    int speed = 100;
    for (uint8_t i = 0; i <= 16; ++i) {
        leds->bitmap(i);
        audio->beep(1, 450);
        nrf_delay_ms(50);
    }
    leds->set(LED_I, ON);
    audio->beep(1, 450);
    nrf_delay_ms(50);
    leds->set(LED_Z, ON);
    audio->beep(1, 450);
    nrf_delay_ms(50);
    leds->set(LED_C, ON);
    audio->beep(1, 450);
    nrf_delay_ms(50);
    leds->set(LED_D, ON);
    audio->beep(1, 450);
    nrf_delay_ms(50);
    leds->allOff();
    audio->beep(1, 450);
    nrf_delay_ms(300);
    leds->allOn();
    audio->beep(1, 450);
    nrf_delay_ms(300);
    leds->allOff();
    audio->beep(1, 450);

    PIXEL colors[] = { { 0, 64, 96 }, { 128, 160, 192}};
    pixels->setColor(0, colors[0]);
    pixels->setColor(1, colors[1]);
    pixels->show();

    bool goDown = false;
    int curLED = LED_D;
    for (int i = 0; i < 20; i++) {
        if (!goDown && curLED > 0) {
            leds->set((LEDS)(curLED - 1), OFF);
        }
        if (goDown && curLED < 4) {
            leds->set((LEDS)(curLED + 1), OFF);
        }
        leds->set((LEDS)curLED, ON);
        nrf_delay_ms(40);

        if (goDown) {
            if (curLED == LED_D) {
                goDown = false;
            } else {
                curLED -= 1;
            }
        } else {
            if (curLED == LED_A) {
                goDown = true;
            } else {
                curLED += 1;
            }
        }
        colors[0].red += 32;
        colors[0].green += 32;
        colors[0].blue += 32;
        colors[1].red += 32;
        colors[1].green += 32;
        colors[1].blue += 32;
        pixels->setColor(0, colors[0]);
        pixels->setColor(1, colors[1]);
        pixels->show();
        audio->beep(1, 425);
    }
    leds->allOff();
    pixels->setColor(0, {0, 1, 0});
    pixels->setColor(1, {0, 1, 0});
    pixels->show();
    audio->beep(50, 800);
    // pwm init + test
    audio->initPWM0();
    audio->setPWM0Ch0Value(0);
    // audio->setPWM0Ch1Value(0);
    audio->setVolume(0);
    audio->enable(false);

    // timer init + test
    audio->initTimer1();

    // Delay for the OLED screen to boot and be ready for commands
    // It needs about 2.5 seconds for reliable operation from a cold power on
    // The above stuff takes up enough time, but make sure you account for this if you change the
    // power on sequence
}

void oled_init(){
    // Setup the display
    SSD1306_begin(SSD1306_SWITCHCAPVCC, SSD1306_I2C_ADDRESS, false);
    SSD1306_setRotation(ROTATION_180);

    // Default text
    util_gfx_init();
    util_gfx_set_font(FONT_COMPUTER_12PT);
    util_gfx_set_cursor(10, 1);
    util_gfx_print("DCZia", COLOR_WHITE);
    util_gfx_set_font(FONT_MONO55_8PT);
    util_gfx_set_cursor(10, 18);
    util_gfx_print("DEFCON 27", COLOR_WHITE);
    util_gfx_draw_dczia(95, 2, COLOR_WHITE);

    // Display the thing
    SSD1306_display();
    nrf_delay_ms(1500);
}

uint8_t tof_pitch(uint8_t prevRange) {
    // read right sensor
    uint8_t range = TOF->readRange(TOF_SENSOR1);

    // Enable this to smooth the sampling a bit
    // range = uint8_t(uint16_t(range + prevRange) >> 1);

    // set pitch with right sensor
    // range_2mm splits range into 2mm chunks
    // +1 prevents divide by 0 x_x
    uint8_t range_2mm = (range >> 1) + 1;
    uint8_t prevRange_2mm = (prevRange >> 1) + 1;

    // only change timer/pitch if hand position changes
    if (range_2mm == prevRange_2mm) {
        return prevRange;
    }
    // check if range is around max (255mm)
    if (range >= 250) {
        audio_off();
        return range;
    }

    // if no, get note that corresponds hand position
    // calculate hand position
    // TOF sensor dies off around 17cm
    uint8_t handPosition = 0;
    if (range_2mm > 57) {  // about 11cm...could be higher
        handPosition = 48;
    } else if (range_2mm >= 10) {  // 2cm of padding close to the sensor
        handPosition = range_2mm - 10;  // start hand position calc at 2cm
    }

    bool halfNote = handPosition & 0x1;  // check if this is an inbetween note
    uint8_t noteIndex = handPosition >> 1;  // divide hand position by 2 to get note

    // if note is beyond current octave, move to next octave
    octavesUp = 0;
    if (noteIndex > 12) {
        noteIndex -= 12;
        octavesUp = 1;
    }

    // get period from note lookup
    uint32_t newPeriod = 0;
    if (halfNote) {
        // get note between (note + (next_note))/ 2
        newPeriod = (notes[octave + octavesUp - 1][noteIndex] + notes[octave + octavesUp - 1][noteIndex + 1]) >> 1;
    } else {
        newPeriod = notes[octave + octavesUp - 1][noteIndex];
    }

    // set new timer1 period
    audio->setTimerWithPeriod_us(newPeriod);
    // make sure timer1 is enabled
    if (!audio->isEnabled()) {
        audio->enable(true);
    }
    // store current hand distance
    return range;
}

uint8_t tof_volume(uint8_t prevRange) {
    // read left sensor
    uint8_t range = TOF->readRange(TOF_SENSOR2);

    uint8_t range_cm = range / 10 + 1;
    uint8_t prevRange_cm = prevRange / 10 + 1;

    if (range_cm == prevRange_cm) {
        return prevRange;
    }

    if (range == 255) {
        audio->setVolume(0);
        return range;
    }

    uint8_t newVolume = range_cm;
    if (newVolume > 16) {
        newVolume = 16;
    }

    audio->setVolume(newVolume);
    return range;
}

//
// Light modes
//
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

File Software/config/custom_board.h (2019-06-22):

/**
 *
 * @file custom_board.h
 *
 * @date June 15 2019
 * @author hamster
 *
 * This is the custom board defines for the LEDs and etc
 *
 */

#ifndef DCZIA_H
#define DCZIA_H

// Setting to zero disables the Nordic initializers
#define LEDS_NUMBER    		0
#define BUTTONS_NUMBER      0


/***
 *      _     _____ ____
 *     | |   | ____|  _ \ ___
 *     | |   |  _| | | | / __|
 *     | |___| |___| |_| \__ \
 *     |_____|_____|____/|___/
 *
 */
#define LED_D_PIN     	23
#define LED_C_PIN       20
#define LED_Z_PIN       21
#define LED_I_PIN       16
#define LED_A_PIN       14

/***
 *      ____        _   _
 *     | __ ) _   _| |_| |_ ___  _ __  ___
 *     |  _ \| | | | __| __/ _ \| '_ \/ __|
 *     | |_) | |_| | |_| || (_) | | | \__ \
 *     |____/ \__,_|\__|\__\___/|_| |_|___/
 *
 */
#define BUTTON_D_PIN    24
#define BUTTON_C_PIN    22
#define BUTTON_Z_PIN    19
#define BUTTON_I_PIN    17
#define BUTTON_A_PIN    15
#define ENC_SW_PIN      5
#define ENC_A_PIN       9
#define ENC_B_PIN       (32 + 15)
#define ENC_C_PIN       7

#define BUTTON_PRESSED 	        0
#define BUTTONS_ACTIVE_STATE    0

/***
 *      _   _   _    ____ _____
 *     | | | | / \  |  _ \_   _|
 *     | | | |/ _ \ | |_) || |
 *     | |_| / ___ \|  _ < | |
 *      \___/_/   \_\_| \_\|_|
 *
 */
#define RX_PIN          6
#define TX_PIN          8
#define CTS_PIN         NRF_UART_PSEL_DISCONNECTED
#define RTS_PIN         NRF_UART_PSEL_DISCONNECTED
#define HWFC           false

/***
 *      _ ____
 *     (_)___ \ ___
 *     | | __) / __|
 *     | |/ __/ (__
 *     |_|_____\___|
 *
 */
#define I2C_SDA_PIN     25
#define I2C_SCL_PIN     26

/***
 *      ____  ____ ___
 *     / ___||  _ \_ _|
 *     \___ \| |_) | |
 *      ___) |  __/| |
 *     |____/|_|  |___|
 *
 */
#define SPI_MISO_PIN    1
#define SPI_SCK_PIN     2
#define SPI_MOSI_PIN    (32 + 12)
#define SPI_SD_CS_PIN   (32 + 13)

/***
 *      ____                          ____
 *     |  _ \ __ _ _ __   __ _  ___  / ___|  ___ _ __  ___  ___  _ __
 *     | |_) / _` | '_ \ / _` |/ _ \ \___ \ / _ \ '_ \/ __|/ _ \| '__|
 *     |  _ < (_| | | | | (_| |  __/  ___) |  __/ | | \__ \ (_) | |
 *     |_| \_\__,_|_| |_|\__, |\___| |____/ \___|_| |_|___/\___/|_|
 *                       |___/
 */
#define TOF1_SHUTDOWN_PIN   11
#define TOF2_SHUTDOWN_PIN   27

/***
 *         _             _ _
 *        / \  _   _  __| (_) ___
 *       / _ \| | | |/ _` | |/ _ \
 *      / ___ \ |_| | (_| | | (_) |
 *     /_/   \_\__,_|\__,_|_|\___/
 *
 */
#define AUDIO_SHUTDOWN_PIN  (32 + 14)
#define AUDIO_HP_DETECT_PIN 13
#define AUDIO_PWM_PIN       3

/***
 *      ____  _          _
 *     |  _ \(_)_  _____| |___
 *     | |_) | \ \/ / _ \ / __|
 *     |  __/| |>  <  __/ \__ \
 *     |_|   |_/_/\_\___|_|___/
 *
 */
#define PIXELS_DOUT_PIN   (32 + 9)

/***
 *      ____  _           _
 *     |  _ \(_)___ _ __ | | __ _ _   _
 *     | | | | / __| '_ \| |/ _` | | | |
 *     | |_| | \__ \ |_) | | (_| | |_| |
 *     |____/|_|___/ .__/|_|\__,_|\__, |
 *                 |_|            |___/
 */
// It's a 128x32 OLED display with a SSD1306 driver
#define SSD1306_128_32

/***
 *     __     __
 *     \ \   / /__  ___ _ __  ___  ___
 *      \ \ / / __|/ _ \ '_ \/ __|/ _ \
 *       \ V /\__ \  __/ | | \__ \  __/
 *        \_/ |___/\___|_| |_|___/\___|
 *
 */
#define VOLTAGE_SENSE_PIN		NRF_SAADC_INPUT_AIN2    // P0.04

//// Clock
//// Low frequency clock source to be used by the SoftDevice
//// We're using the internal RC osc
/*#define NRF_CLOCK_LFCLKSRC      {.source        = NRF_CLOCK_LF_SRC_RC, \
                                 .rc_ctiv       = 16, \
                                 .rc_temp_ctiv  = 2, \
                                 .xtal_accuracy = NRF_CLOCK_LF_XTAL_ACCURACY_20_PPM} */



#endif // DCZIA_H

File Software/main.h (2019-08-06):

/**
 *
 * @file main.h
 *
 * @date June 20 2019
 * @author hamster
 *
 * Main header file
 *
 */

#ifndef MAIN_H_
#define MAIN_H_

#include <stdint.h>
#include "./common.h"

// Includes for our app
#include "./utility.h"
#include "./modules/audio.h"
#include "./modules/ble.h"
#include "./modules/sd.h"
#include "./modules/adc.h"
#include "./modules/uart.h"
#include "./modules/i2c.h"
#include "./modules/led.h"
#include "./modules/gfx.h"
#include "./modules/drv_ssd1306.h"
#include "./modules/VL6180X.h"
#include "./modules/ws2812b.h"
#include "./modules/SAO.h"

#define VERSION "1.00"
#endif /* MAIN_H_ */

typedef enum {
    BUTTON_PRESS_D = 1,
    BUTTON_PRESS_C = 2,
    BUTTON_PRESS_Z = 3,
    BUTTON_PRESS_I = 4,
    BUTTON_PRESS_A = 5
} BUTTON_PRESS;

/* badge modes */
const uint8_t BADGE_MODE_DEFAULT   = 0;
const uint8_t BADGE_MODE_THEREMIN  = 1;
const uint8_t BADGE_MODE_FIXED_VOL = 2;
const uint8_t BADGE_MODE_CREDITS   = 3;
const uint8_t BADGE_MODES          = 4;

void audio_off();
void incrementBadgeMode();
void button_handler(nrf_drv_gpiote_pin_t pin, nrf_gpiote_polarity_t action);
void startup_sequence();
void checkButtonHolds();
void checkSAO();
void modeSet(BUTTON_PRESS buttonPress);

void led_theramin();
void led_handler_cylon(void *p_context);
void led_animation(uint16_t led_speed);

void e1m1();
void noteDoomBase(int octave, int speed, int volume);
uint8_t tof_pitch(uint8_t prevRange);
uint8_t tof_volume(uint8_t prevRange);
void oled_init();

APP_TIMER_DEF(m_led_timer_id);
APP_TIMER_DEF(m_audio_step_timer_id);
void audio_timer_handler(void *p_context);

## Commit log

2019-03-26 Added basis for PWM sdk code
2019-03-26 Fixed led code, removed some pwm stuff to get build working
2019-03-26 IT BEEEPSgit add ../../.! Speaker on pin 3
2019-03-26 Added PWM Driver Code, changed makefile and sdk.h
2019-05-15 Add hardware design files
    [12mm Incremental Encoder - BOURNS PEC11S - No Knob.STEP, 12mm Incremental Encoder - BOURNS PEC11S.stp, BMD-340.STEP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]
2019-06-03 Adding design files and outputs for proto1 and proto2
    [laser-theremin-B_CrtYd.gbr, laser-theremin-B_Cu.gbl, laser-theremin-B_Fab.gbr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]
2019-06-18 Updating design to final
    [DCZIA DC27 BADGE BOM.xlsx, Seeed BOM.xlsx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]
2019-06-22 Adding and updating code to support the prototype board at a base level More work to be done here, but this gets things started
2019-06-29 add PWM functionality
2019-07-03 add timer support. add support for distance sensors controlling frequency and amplitude
2019-07-07 fix pwm count bug to go all the way; increase timer and pwm speeds; change pwm and timer to control audio instead of LEDs
    [audio.cpp, main.cpp]
2019-07-08 rewrite button detect to support simultaneous presses
2019-07-21 Mixed tabs/spaces and trailing spaces fix
    [main.cpp, utility.cpp]
2019-07-28 added LED theramin mode
2019-07-29 Lighting slowing coming together. Fixed A led issue
    [audio.cpp, main.cpp, main.h]
2019-08-01 add encoder support and make buttons interrupt driven
2019-08-02 Fix formatting using cpplint to check
    [main.cpp, main.h]
2019-08-02 Add bitmap method of setting LEDs
2019-08-02 Reduce led_mode 3 size
2019-08-03 restructure doom playback to use interrupts
2019-08-03 add short debounce for buttons
    [main.cpp]
2019-08-03 cleaned up some light modes 👾
2019-08-03 add new waveforms selected by buttons
2019-08-04 add ability to change octave with encoder
2019-08-06 Update BLE Name so it is readable in scanners. Removed one of the (many) printf buffer overflows for the name.
2019-08-08 Added ligt mode fixes
    [main.cpp]
